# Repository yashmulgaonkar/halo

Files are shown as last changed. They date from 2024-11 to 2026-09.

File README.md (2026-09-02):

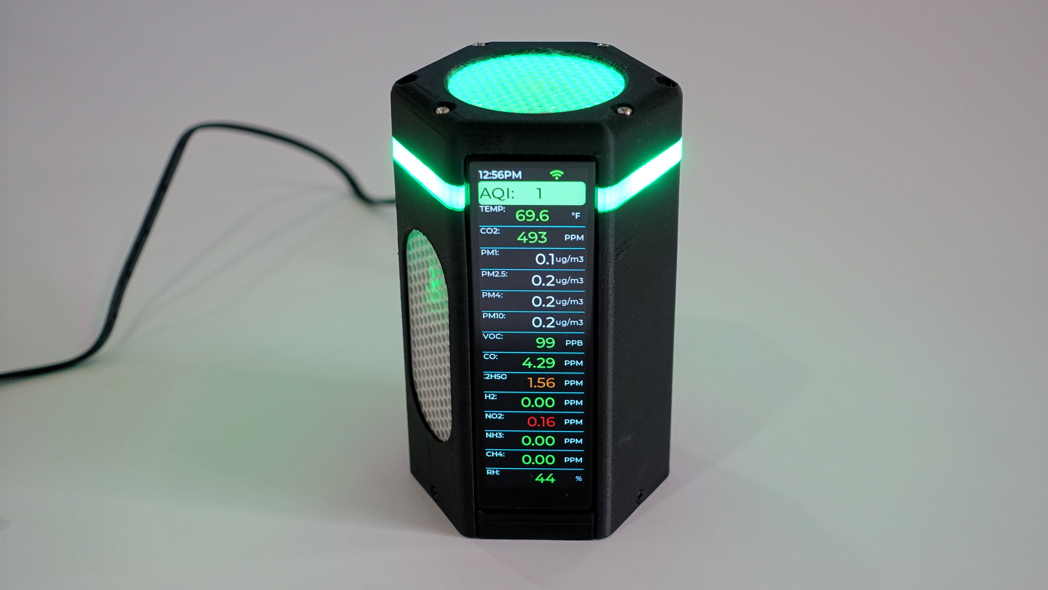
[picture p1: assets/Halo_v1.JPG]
Halo_v1


# HALO: The Air Quality Sensor That Smells Trouble Before You Do

Welcome to HALO — your hilariously over-engineered, open-source buddy who sniffs the air so you don’t have to. Designed for folks who care about the air they breathe but also want a sensor with personality, HALO operates on WiFi via ESPHome, which means no creepy cloud subscriptions or hidden fees. It’s just you, HALO, and your dusty air duking it out together.

---

## Features? Oh, HALO’s Got a Few Good Ones:

- **PM (Particulate Madness):** HALO tracks dust, pollen, and those mysterious floating things in the air. From “small but annoying” (PM2.5) to “call-the-vacuum” (PM10), HALO’s on it.
- **Sniffs Like a Dog:** HALO detects VOCs, CO₂, and gases like Ammonia, Ethanol, Methane, and Hydrogen. Basically, it’s like having a science lab shoved into a tiny box.
- **Weather Nerd:** HALO keeps tabs on temperature, humidity, and air pressure. It’s not your local weather station — it’s cooler.
- **Party Mode:** An eleven RGB LED HALO for air quality notifications or impromptu raves. Who said clean air can’t be fun?
- **Bluetooth Tracker:** HALO can help automate your home or, you know, find your keys if they’re Bluetooth-enabled.
- **Bluetooth & WiFi Powerhouse:** Includes BLE 5 + BT Mesh for seamless device integration and WiFi connectivity so HALO is always in the loop.
- **Touch of Brilliance:** A shiny new 3.4″ 640px × 180px LCD touchscreen for easy navigation and monitoring. Control HALO like a pro without even opening an app!

---

## Hardware Components

HALO is built with a powerhouse of components designed to sniff out, measure, and display air quality data with style. Here’s what makes HALO tick:

### MCU (Microcontroller Unit)
- **LILYGO T-Display-Long-S3:** The brains behind HALO, featuring an ESP32S3, a Dual-core LX7 MCU with a 3.4″ LCD touchscreen for easy interaction and a whole lot of smarts.

### Sensors
- **SCD-41:**
  - Measures CO₂ levels so you know when to crack a window open.
  - Tracks temperature because no one likes surprises.
  - Monitors humidity to keep your comfort levels in check.
- **SEN54 (or SEN55):**
  - Detects particulate matter: PM1, PM2.5, PM4, and PM10 (basically, HALO counts all the tiny stufflets floating around).
  - Measures VOC (Volatile Organic Compounds) to warn you about sketchy smells.
  - Also tracks temperature and humidity for full environmental awareness.
- **BME280:**
  - Keeps tabs on temperature, pressure, and humidity, because precision matters.
- **MIC4514:**
  - Sniffs out gases like:
    - CO (Carbon Monoxide)
    - C₂H₅OH (Ethanol)
    - H₂ (Hydrogen)
    - NO₂ (Nitrogen Dioxide)
    - NH₃ (Ammonia)
    - CH₄ (Methane)
- **Neopixels (11-LED ring):**
  - Side-fire **SK68XX-EC3210F** ([Adafruit #4892](https://cdn-shop.adafruit.com/product-files/4892/4892_SK68XX-EC3210F__REV.A.pdf)) — `NEO_GRB` + `NEO_KHZ800` / WS2812-compatible on GPIO47.

---

## Plug & Play? More Like Plug & Pray (Kidding — It’s Easy):

1. **Power Up:** Plug HALO into a decent USB-C power brick. If HALO starts rebooting like it’s stuck in a bad WiFi loop, blame your cheap charger. HALO deserves better.
2. **Find HALO’s Hotspot:** Look for the “HALO’s AP” network on your phone or computer. Connect, and voilà — HALO’s dashboard appears. If it doesn’t, just type `http://192.168.4.1`. Because nothing says “high-tech” like typing an IP address.
3. **Join Your WiFi:** Tell HALO your WiFi name and password. Pro tip: Maybe don’t name your WiFi “NSA Surveillance Van.” HALO’s judgment-free, but still.

---

## Home Assistant Integration: Because HALO Plays Well With Others

1. Add HALO to Home Assistant using ESPHome.
2. When prompted, click things like “Adopt” and “Submit.” It’s basically adopting a pet rock, except HALO is useful.
3. Give HALO a home area (kitchen, bedroom, dungeon — no judgment).

---

## What Does HALO Measure? Everything.

- **Particulates:** PM10, PM2.5, PM4, and PM1 – tiny ones you didn’t know existed. HALO’s the Sherlock Holmes of dust.
- **Gases:** From Nitrogen Dioxide (NO₂) to the Ammonia from your cat’s litter box, HALO’s got a nose for trouble.
- **Humidity & Temp:** Whether you’re sweating or freezing, HALO knows.
- **CO₂:** If your room feels stuffy, HALO will call you out.

---

## Fun Extras:

- **RGB Light Show:** HALO’s RGB LED halo can flash when your air quality is trash. It’s like HALO’s saying, “Get it together, human!”
- **Self-Calibrating Genius:** Just take HALO outside, and it’ll calibrate itself. HALO loves fresh air, too.

### Calibration & packages

- Sensor calibration (CO₂ ASC, SEN55 heat offsets, fan clean, NowCast): see [`TFT_LCD/T-Display-Long/V1/Firmware/ESPHome/CALIBRATION.md`](TFT_LCD/T-Display-Long/V1/Firmware/ESPHome/CALIBRATION.md)
- Optional modular packages (BLE stub, offline AQI history, weather, WireGuard): see [`TFT_LCD/T-Display-Long/V1/Firmware/ESPHome/PACKAGES.md`](TFT_LCD/T-Display-Long/V1/Firmware/ESPHome/PACKAGES.md)

---

## Troubleshooting? Call the HALO Hotline (AKA, Join Our Discord)

If HALO misbehaves, pop into our Discord for tips, tricks, and memes. HALO doesn’t judge your air, so don’t judge HALO’s quirks.

---

## Why HALO?

Because life’s too short for bad air and boring gadgets. HALO makes clean air monitoring fun, fabulous, and a little ridiculous.

### Open-Source for Open Minds
We love tinkerers, dreamers, and anyone who thinks, “You know what HALO really needs? A coffee maker attachment.” That’s why we’ve shared HALO’s software and CAD files with the world. Dive into our GitHub, unleash your inner mad scientist, and share your creations on Discord. Who knows? Your idea might just inspire HALO 2.0.

- **Build Instructions:** [https://github.com/yashmulgaonkar/halo/wiki](https://github.com/yashmulgaonkar/halo/wiki)
- **Discord:** [HALO Community](https://discord.gg/wjqgUjv8Re)

---

<div align="center"><strong>HALO: The sensor you didn’t know you needed — but now can’t live without.</strong></div>

---
<p align="center">
  <a href="https://buymeacoffee.com/yashmulgaonkar" target="_blank">
    Buy Me a Coffee
  </a>
</p>

---

Repo analytics (https://github.com/yashmulgaonkar/repo-analytics)

Repobeats analytics image

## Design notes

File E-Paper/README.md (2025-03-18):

Folder for Halo with an E-Paper display

The EPD version of Halo will use a [tricolor display from Waveshare](https://www.waveshare.com/2.9inch-e-paper-module-b.htm?&aff_id=108718) paired with a [ESP32-S3-Zero](https://www.waveshare.com/esp32-s3-zero.htm?sku=25517&aff_id=108718)

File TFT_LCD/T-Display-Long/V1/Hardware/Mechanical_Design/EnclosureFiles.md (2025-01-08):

# Halo AQI Enclosure Files

All 3D print files for the enclosure are available on the following platforms:





---

### How to Use These Files
1. Click one of the buttons above to access the 3D print files on your preferred platform.
2. Download the STL/STEP files.
3. Print the parts using your 3D printer and filaments of choice.
4. Assemble the enclosure following the project documentation on the [Halo Wiki](https://github.com/yashmulgaonkar/halo/wiki).

### Feedback and Contributions
Feel free to open an issue or submit a pull request if you encounter any issues or have suggestions for improvements.

---

### License
This project is licensed under the MIT License. See the [LICENSE](https://github.com/yashmulgaonkar/halo/blob/main/LICENSE) file for details.

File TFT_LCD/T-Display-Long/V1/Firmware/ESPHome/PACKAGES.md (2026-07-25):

# Modular packages (HALO)

## Cause of "Duplicate switch ... Startup Light Blink"

That switch lives only in `Halo-v1-Core.yaml`. It is duplicated when Core is
merged **twice**, usually because the device YAML `files:` list includes both:

- `Halo-v1.yaml` (which already pulls in Core), and
- `Halo-v1-Core.yaml` (again)

List **either** the entry file **or** the leaf packages — never both.

## Home Assistant — preferred (leaf packages once)

The NeoPixel driver lives at repo-root `components/ws2812_bitbang`.
HA leaf installs must load it via `external_components` **before** the packages
block (local `path:` only works for USB builds from this folder).

```yaml
esphome:
  name: halo-v1-4d1658
  friendly_name: Halo Air Quality Sensor 4d1658
  name_add_mac_suffix: false
  min_version: 2026.7.2

external_components:
  - source: github://yashmulgaonkar/halo@main
    components: [ws2812_bitbang]

ota:
  - platform: esphome
    id: ota_default

wifi:
  power_save_mode: none
  use_psram: true
  ap:
    ssid: "Halo Hotspot"

packages:
  remote_package:
    url: https://github.com/yashmulgaonkar/halo/
    ref: main
    refresh: 1d
    files:
      - TFT_LCD/T-Display-Long/V1/Firmware/ESPHome/packages/base/globals.yaml
      - TFT_LCD/T-Display-Long/V1/Firmware/ESPHome/packages/system/esphome_core.yaml
      - TFT_LCD/T-Display-Long/V1/Firmware/ESPHome/packages/features/ble/ble_stub.yaml
      - TFT_LCD/T-Display-Long/V1/Firmware/ESPHome/packages/features/airq/airq_history.yaml
      - TFT_LCD/T-Display-Long/V1/Firmware/ESPHome/packages/features/page_rotation/page_rotation.yaml
      - TFT_LCD/T-Display-Long/V1/Firmware/ESPHome/packages/features/ota/ota_channel.yaml
      - TFT_LCD/T-Display-Long/V1/Firmware/ESPHome/Halo-v1-Core.yaml
```

Do **not** add `Halo-v1.yaml` to that `files:` list.

Use `ble_improv.yaml` instead of `ble_stub.yaml` only when you need Improv
Wi-Fi provisioning (Bluedroid can worsen LED flicker under heavy radio load).

## Local / CI

[`Halo-v1.yaml`](Halo-v1.yaml) and [`Halo-v1-dev.yaml`](Halo-v1-dev.yaml) use
sibling `!include`s from this directory and a local `external_components` path
to `components/ws2812_bitbang` at the repo root.

```
packages/
  base/globals.yaml
  system/esphome_core.yaml
  features/ble/{ble_improv,ble_stub}.yaml
  features/airq/airq_history.yaml
  features/page_rotation/page_rotation.yaml
  features/ota/ota_channel.yaml
  features/weather/weather_ha.yaml      # optional
  features/wireguard/wireguard.yaml     # optional
```

Calibration: [`CALIBRATION.md`](CALIBRATION.md).

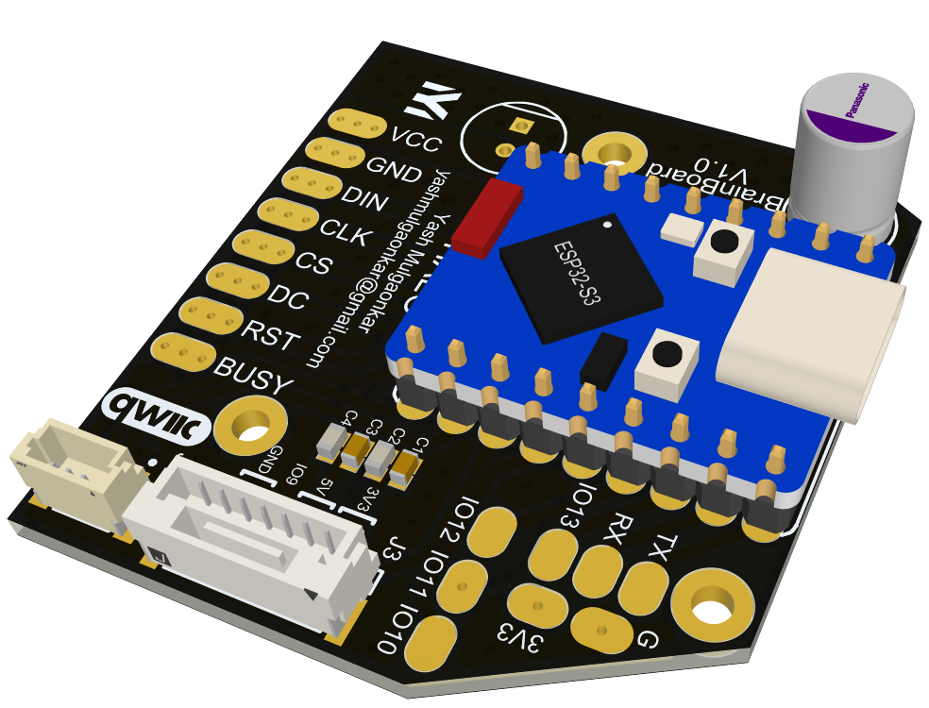
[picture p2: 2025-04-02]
E-Paper/Waveshare_BWR/V1/Hardware/Electrical_Design/BrainBoard/V1.0/Halo_BrainBoard_V1.0.png

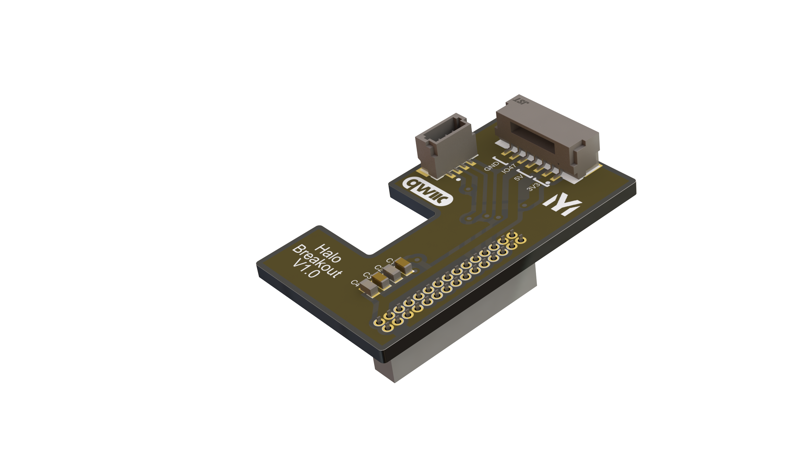
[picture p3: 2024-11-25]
TFT_LCD/T-Display-Long/V1/Hardware/Electrical_Design/Breakout/Halo_Breakout_V1.0.png

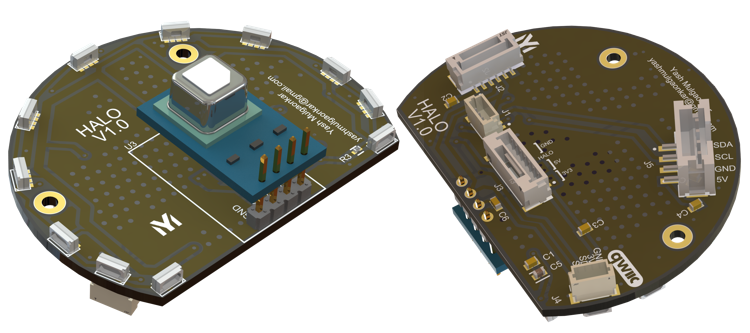
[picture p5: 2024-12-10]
assets/Halo_MainBoard_V1.0_1.png

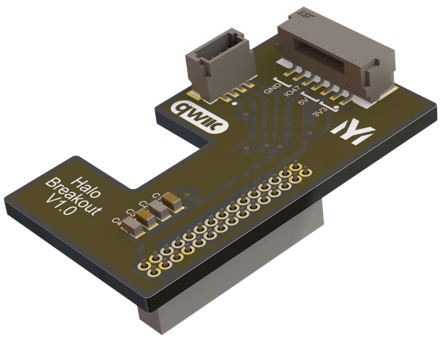
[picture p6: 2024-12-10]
assets/Halo_Breakout_V1.0.jpg

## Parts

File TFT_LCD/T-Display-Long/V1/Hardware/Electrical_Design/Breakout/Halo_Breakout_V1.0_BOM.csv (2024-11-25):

Designator | Quantity | Manufacturer | Manufacturer Part Number | Description
C1, C3 | 2 | YAGEO | CC0603ZRY5V9BB104 | 0.1 µF -20%, +80% 50V Ceramic Capacitor Y5V (F) 0603 (1608 Metric)
C2, C4 | 2 | YAGEO | CC0603KRX5R8BB105 | 1 µF ±10% 25V Ceramic Capacitor X5R 0603 (1608 Metric)
J1 | 1 | JST Sales America Inc. | SM07B-GHS-TB | Connector Header Surface Mount, Right Angle 7 position 0.049" (1.25mm)
J2 | 1 | JST Sales America Inc. | BM04B-SRSS-TBT | Connector Header Surface Mount 4 position 0.039" (1.00mm)
J3 | 1 | Amphenol ICC (FCI) | 20021311-00030T4LF | 30 Position Receptacle Connector 0.050" (1.27mm) Through Hole Gold

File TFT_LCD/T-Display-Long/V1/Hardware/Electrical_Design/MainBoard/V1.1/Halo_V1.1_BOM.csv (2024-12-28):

Designator | Quantity | Manufacturer | Manufacturer Part Number | Description
C1, C2, C3, C4, C6 | 5 | YAGEO | CC0603ZRY5V9BB104 | 0.1 µF -20%, +80% 50V Ceramic Capacitor Y5V (F) 0603 (1608 Metric)
C5 | 1 | Murata Electronics | GRM188R6YA106MA73D | 10 µF ±20% 35V Ceramic Capacitor X5R 0603 (1608 Metric)
J1, J4 | 2 | JST Sales America Inc. | BM04B-SRSS-TBT | Connector Header Surface Mount 4 position 0.039" (1.00mm)
J2 | 1 | JST Sales America Inc. | BM06B-GHS-TBT | Connector Header Surface Mount 6 position 0.049" (1.25mm)
J3 | 1 | JST Sales America Inc. | BM07B-GHS-TBT | Connector Header Surface Mount 7 position 0.049" (1.25mm)
J5 | 1 | JST Sales America Inc. | B4B-PH-SM4-TB | Connector Header Surface Mount 4 position 0.079" (2.00mm)
LED1, LED2, LED3, LED4, LED5, LED6, LED7, LED8, LED9, LED10 | 10 | Adafruit | 1655 | NeoPixel 5050 RGB LED with Integrated Driver
R3 | 1 | Vishay Dale | CRCW0402470RFKED | 470 Ohms ±1% 0.063W, 1/16W Chip Resistor 0402 (1005 Metric) Automotive AEC-Q200 Thick Film
U3 | 1 | Sensirion | SCD41 | HiLetgo SCD41 CO2 Carbon Dioxide Sensor (Amazon 14mm x 20mm modules)
U1 | 1 | Adafruit | 2226 | NeoPixel Jewel - 7 x 5050 RGB LED with Integrated Drivers

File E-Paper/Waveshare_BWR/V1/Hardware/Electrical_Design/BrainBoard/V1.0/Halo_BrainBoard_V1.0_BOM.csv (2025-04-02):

Designator | Quantity | Footprint | Manufacturer Part Number | Digi-Key Part Number | Comment
C1, C3 | 2 | CAPC1608X90X40LL10T20 |  |  | CC0603ZRY5V9BB104
C2, C4 | 2 | CAPC1608X90X35LL10T15 |  |  | GRM188R61E105KA12D
C5, C6 | 2 | FP-OS-CON-TH-C9-d_0_6-MFG |  |  | 6SEPC470MW+TSS
J2 | 1 | FP-BM04B-SRSS-TBT_LF_SN-MFG |  |  | BM04B-SRSS-TBT
J3 | 1 | FP-BM07B-GHS-TBT_LF_SN-MFG |  |  | BM07B-GHS-TBT (LF)(SN)
TP1, TP2, TP3, TP4, TP5, TP6, TP7, TP8 | 8 | test_pad |  |  | test_pad
U1 | 1 | ESP32-S3-Zero_headers |  |  | ESP32-S3-Zero
U2 | 1 | EPD |  |  | EPD

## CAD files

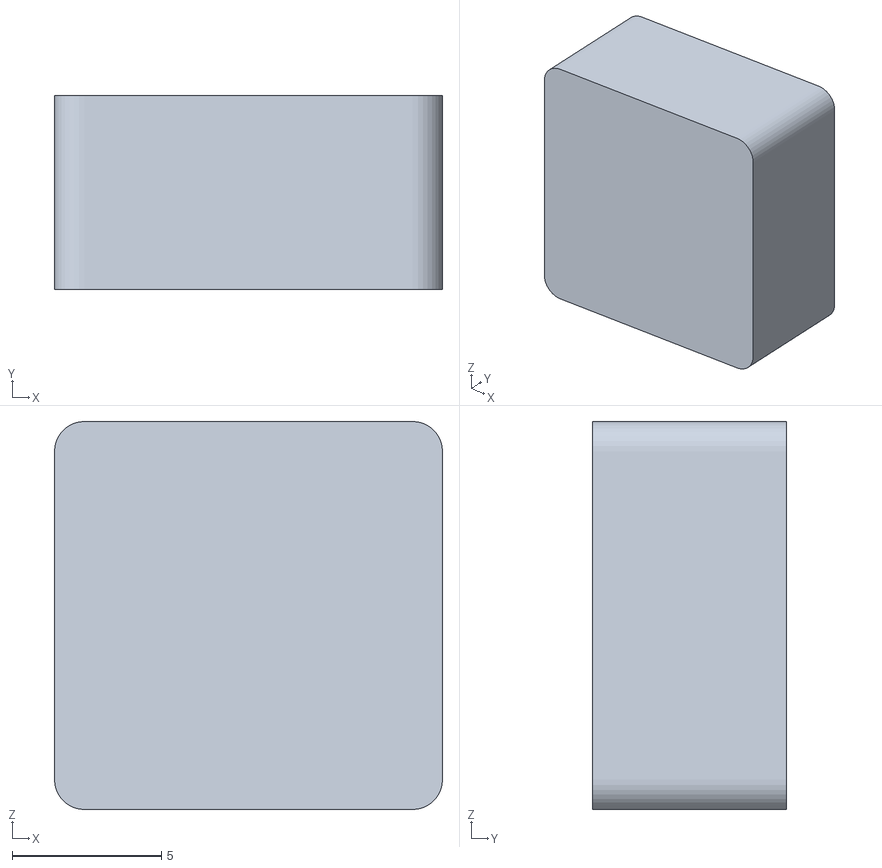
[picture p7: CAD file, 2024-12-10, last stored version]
V1/Hardware/Mechanical_Design/STLs/HALO_CO2_spacer.STL
13.0 x 6.50 x 13.0

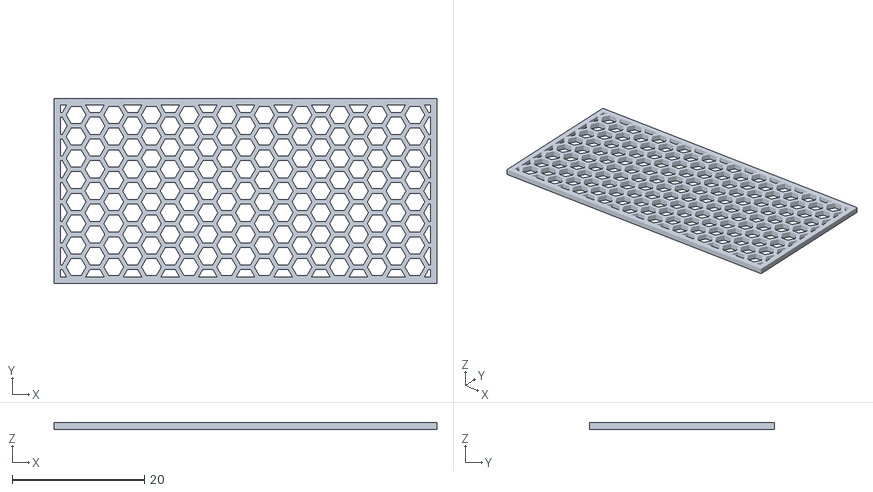
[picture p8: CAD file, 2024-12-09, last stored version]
V1/Hardware/Mechanical_Design/STLs/HALO_side_mesh.STL
58.0 x 28.0 x 1.00

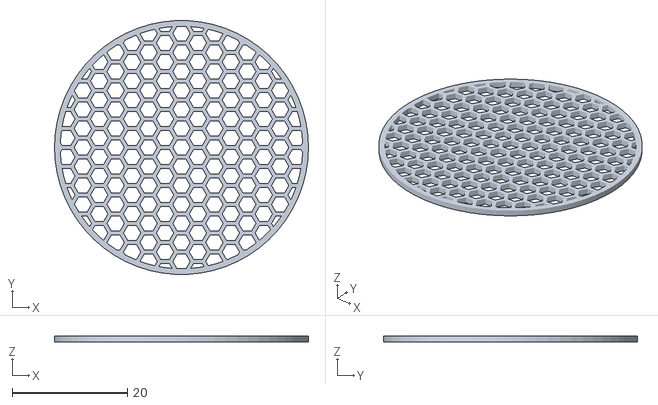
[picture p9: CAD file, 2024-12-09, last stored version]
V1/Hardware/Mechanical_Design/STLs/HALO_top_mesh.STL
44.0 x 43.9 x 1.00

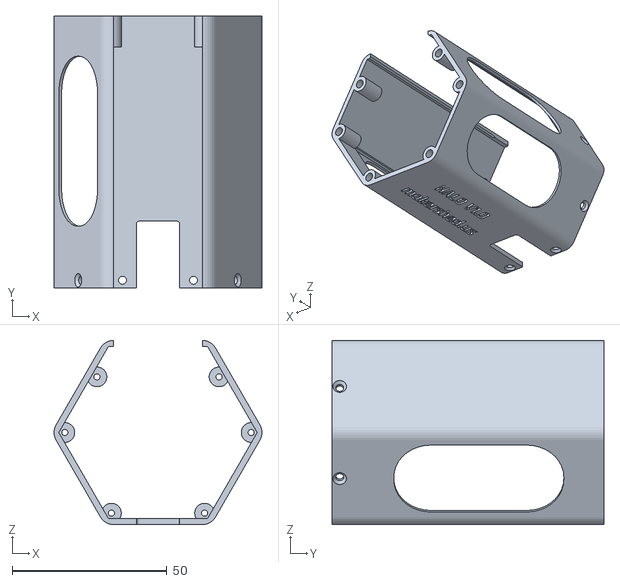
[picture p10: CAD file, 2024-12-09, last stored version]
V1/Hardware/Mechanical_Design/STLs/HALO_outer_shell.STL
67.3 x 88.0 x 59.6

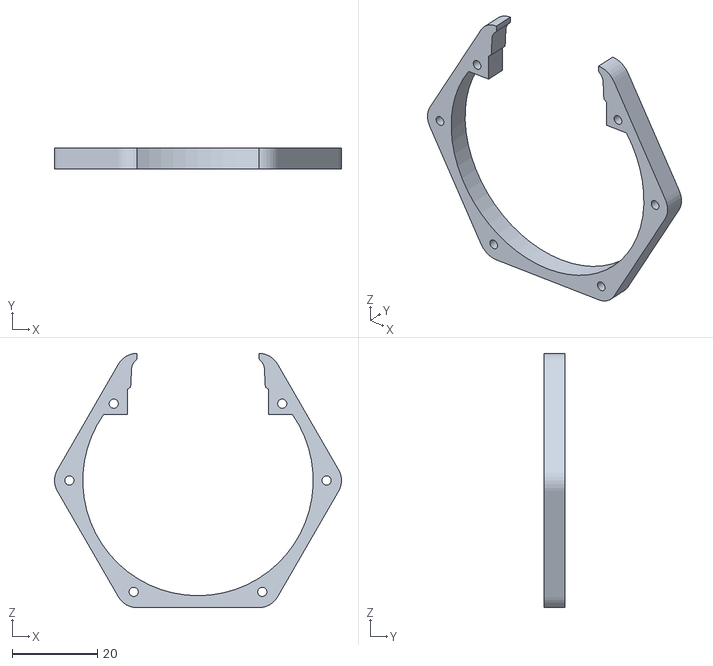
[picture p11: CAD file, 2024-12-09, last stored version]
V1/Hardware/Mechanical_Design/STLs/HALO_light_diffuser.STL
67.3 x 5.00 x 59.6

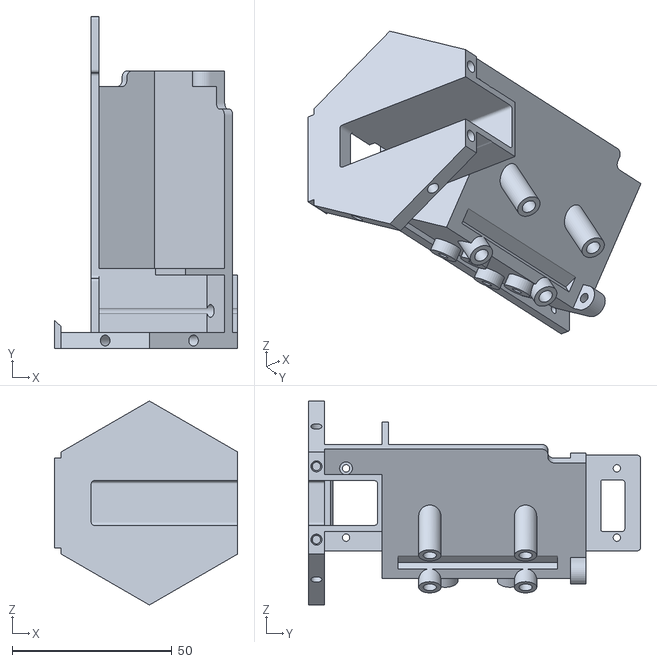
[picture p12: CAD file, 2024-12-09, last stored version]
V1/Hardware/Mechanical_Design/STLs/HALO_base.STL
57.5 x 104.0 x 63.9

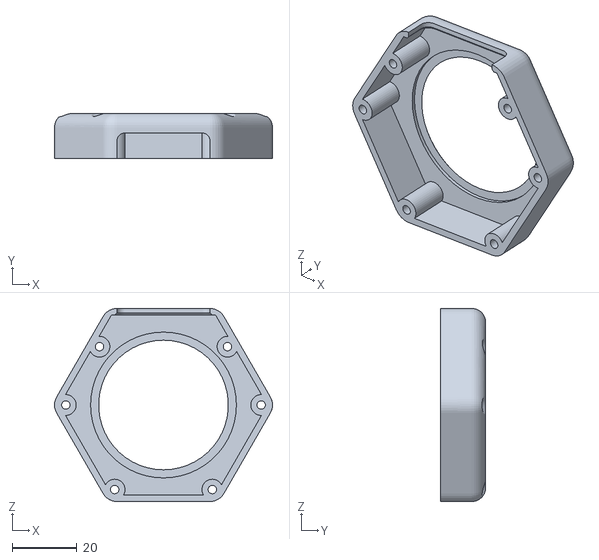
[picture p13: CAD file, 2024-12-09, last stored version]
V1/Hardware/Mechanical_Design/STLs/HALO_top_cap.STL
67.3 x 14.0 x 59.6

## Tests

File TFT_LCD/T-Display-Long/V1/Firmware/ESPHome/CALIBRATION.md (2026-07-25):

# Sensor calibration and heat management (HALO)

HALO shares the same sensor family as many ESPHome air-quality boards
(SCD4x, SEN55, MiCS-4514, BME280). These notes cover the controls exposed
in firmware on branch `feat/community-adoption`.

## CO₂ (SCD4x)

- **Forced calibration:** Home Assistant button `Calibrate SCD40 To 420ppm`,
  or API service `calibrate_co2_value` with a target ppm. Take the device
  outdoors (or to known fresh air) for several minutes before calibrating.
- **Automatic self-calibration (ASC):** Switch `CO2 Auto Calibration`.
  The SCD4x forgets ASC across power loss. HALO uses stop → write ASC →
  start periodic measurement so the command is accepted while idle.
- **Pressure compensation:** CO₂ readings use BME280 pressure as
  `ambient_pressure_compensation_source`.

## SEN55 temperature / humidity

- The USB-powered display board self-heats. Default
  **SEN55 Temperature Offset** is **6.0 °C** (subtracted from the raw
  reading). Tune the offset entity until SEN55 tracks a reference room
  thermometer.
- **SEN55 Humidity Offset** defaults to 0; adjust if RH is systematically
  high/low versus a reference.
- Continuous always-on reporting favors responsiveness over thermal
  settling. If you need better absolute T/RH accuracy, increase airflow
  around the vents and re-tune offsets after a 30+ minute warm-up.

## SEN55 model / NOx / fan clean

- Firmware forces `model: sen55` so NOx stays enabled on modules that
  misreport as SEN54 (requires ESPHome **2026.7.2+**).
- Button **Clean SEN55** (and API `sen55_clean`) runs the fan autoclean cycle.
- VOC index thresholds for the **VOC Quality** text sensor follow Sensirion
  guidance (Improved / Normal / Abnormal / …).

## AQI

- **Computed AQI** on the display is the on-device US EPA PM2.5 banding used
  by the LVGL UI.
- **NowCast AQI** is the native ESPHome `aqi` platform (PM2.5 + PM10) for
  Home Assistant — it does not replace the display math.

## Offline history

When the `airq_history` package is enabled (default), HALO buffers readings
in PSRAM while Home Assistant is unreachable and flushes
`esphome.aqi_history_batch` events on reconnect. Optional AppDaemon ingest
lives under [`HomeAssistant/AppDaemon/apps/`](../../../../HomeAssistant/AppDaemon/apps/).

## MiCS-4514 gases

Treat multi-gas readings as relative indicators, not safety-grade CO or
leak alarms. Cross-sensitivity (especially methane) is expected.

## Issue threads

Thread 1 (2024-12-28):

Missing Components

McRoth73, 2024-12-28:
I'm gathering the parts to make this and noticed that some pieces are missing from the BOM.  I don't see the 30 pin connector for the Lilygo board, whatever the 4 little cubes next to it the pic of it and the, I'm guessing, LED's around the perimeter of the semicircle board.  There may be others that I don't see.  Can you please add these and confirm that there aren't any other missing components?
Also, I ordered the V1.0 boards, are they going to work now that I see there is are V1.1 boards?

yashmulgaonkar, 2024-12-28:
Looks like you are looking for the Breakout board.
All relevant files are here:

https://github.com/yashmulgaonkar/halo/blob/main/V1/Hardware/Electrical_Design/Breakout

Closed 2024-12-28.

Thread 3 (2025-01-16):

ESP Home : Failed to build Error 522 YM.png

jfdl, 2025-01-16:
While trying to install your firmware on my board i got this error 522:

Could not download from https://yashmulgaonkar.com/YM.png: **522 Server Error**:  for url: https://yashmulgaonkar.com/YM.png.
file: https://yashmulgaonkar.com/YM.png

Is your site still online or is it a local issue ?

yashmulgaonkar, 2025-01-16:
This is correct. We have a major power outage so my server is offline at the moment. Please standby.

yashmulgaonkar, 2025-01-16:
I’ll take this as a motivation to move the online files away from a private server to GitHub.

yashmulgaonkar, 2025-01-16:
@jfdl Can you please the latest release now?

jfdl, 2025-01-17:
It is working fine now.
Thanks

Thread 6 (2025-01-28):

PCB Dimensions?

wanball, 2025-01-28:
Sorry for my English.

Can you tell me the dimensions of Halo MainBoard and Halo Breakout?

Since my soldering skill is quite bad, I want to modify the PCB myself to suit my soldering and change some connectors so that I can buy them.

Thanks for your attention.

wanball, 2025-01-28:
I would like to ask one more question, can I increase the thickness to 2mm?

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

yashmulgaonkar, 2025-02-18:
@wanball all PCB CAD files for dimensions are available in the repo.
If you increase the thickness to 2mm, make sure to also increase the clearance in the outer shell  to accommodate the thicker mesh.

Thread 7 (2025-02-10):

Trying to upload bom and pick&place for breakout pcb to JLCPCB

greberg, 2025-02-10:
Hi

Im trying to upload the bom and pick&place files for the breakout card to JLCPCB but when I choose process files I get a error message that says "File processing failed, please check your file and upload again." I wonder if it is any fault into the P&P breakout file. Not sure if it could be about the coordinates?  Maybe it has changed on JLCPCB side?

https://github.com/yashmulgaonkar/halo/blob/main/TFT_LCD/T-Display-Long/V1/Hardware/Electrical_Design/Breakout/Pick%20Place%20for%20Halo_Breakout_V1.0.csv

Best regards
Peter

greberg, 2025-02-11:
Found a new bom file in discord that worked.

https://discord.com/channels/1309649507310506115/1309649802811670669/1333982233605967944

MaffooClock, 2025-04-11:
For anyone attempting to follow the link above, but getting an error, you need to be accepted to the Makershed.us discord first:
https://discord.gg/wjqgUjv8Re

Better yet, I'll save you the trouble just paste the damn CSVs from the above-linked comment:
```csv
Description,Designator,Footprint,JLCPCB Part #,Manufacturer,Manufacturer Part Number
"0.1 µF -20%, +80% 50V Ceramic Capacitor Y5V (F) 0603 (1608 Metric)","C1, C2, C3, C4, C6",C0603,C106221,YAGEO,CC0603ZRY5V9BB104
10 µF ±20% 35V Ceramic Capacitor X5R 0603 (1608 Metric),C5,C0603,C194427,Murata Electronics,GRM188R6YA106MA73D
"Connector Header Surface Mount 4 position 0.039"" (1.00mm)","J1, J4",CONN-SMD_BM04B-SRSS-TBT-LF-SN,C495539,JST Sales America Inc.,BM04B-SRSS-TBT
"Connector Header Surface Mount 6 position 0.049"" (1.25mm)",J2,CONN-SMD_6P-P1.25_BM06B-GHS-TBT-LF-SN-N,C189892,JST Sales America Inc.,BM06B-GHS-TBT
"Connector Header Surface Mount 7 position 0.049"" (1.25mm)",J3,CONN-SMD_SM7B-GHS-TB-LF-SN,C495552,JST Sales America Inc.,BM07B-GHS-TBT
"Connector Header Surface Mount 4 position 0.079"" (2.00mm)",J5,CONN-SMD_B4B-PH-SM4-TB-LF-SN,C160354,JST Sales America Inc.,B4B-PH-SM4-TB
"470 Ohms ±1% 0.063W, 1/16W Chip Resistor 0402 (1005 Metric) Automotive AEC-Q200 Thick Film",R3,R0402,C482182,Vishay Dale,CRCW0402470RFKED
4 pin LED,"LED1, LED2, LED3, LED4, LED5, LED6, LED7, LED8, LED9, LED10",LED-SMD_4P-L5.0-W5.0-LS5.4-TL-1,C5378720,OPSCO Optoelectronics,SK6812
```

```csv
Comment,Designator,Footprint,JLCPCB Part #
"0.1 µF -20%, +80% 50V Ceramic Capacitor Y5V (F) 0603 (1608 Metric)","C1, C3",C0603,C106221
1 µF ±10% 25V Ceramic Capacitor X5R 0603 (1608 Metric),"C2, C4",C0603,C14664
"Connector Header Surface Mount, Right Angle 7 position 0.049"" (1.25mm)",J1,CONN-SMD_SM7B-GHS-TB-LF-SN,C495552
"Connector Header Surface Mount 4 position 0.039"" (1.00mm)",J2,CONN-SMD_BM04B-SRSS-TBT-LF-SN,C495539
"30 Position Receptacle Connector 0.050"" (1.27mm) Through Hole Gold",J3,HDR-TH_30P-P2.54-V-F-R2-C15-S2.54,C9900022973
```

Closed 2025-02-11.

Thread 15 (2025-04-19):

ESPHome Builder: TypeError: spi_device_schema() got an unexpected keyword argument 'quad'

MaffooClock, 2025-04-19:
While following the [Setup Instructions](https://github.com/yashmulgaonkar/halo/wiki/Software-Setup), when I get to the step after I copy the [Halo-v1.yaml](https://github.com/yashmulgaonkar/halo/blob/main/TFT_LCD/T-Display-Long/V1/Firmware/ESPHome/Halo-v1.yaml) to the newly-created device, then attempt to install, I get this:

```text
INFO ESPHome 2025.4.0
INFO Reading configuration /config/esphome/halo.yaml...
INFO Updating https://github.com/yashmulgaonkar/halo/@main
ERROR Unable to load component axs15231.display:
Traceback (most recent call last):
  File "/esphome/esphome/loader.py", line 181, in _lookup_module
    module = importlib.import_module(f"esphome.components.{domain}")
             ^^^^^^^^^^^^^^^^^^^^^^^^^^^^^^^^^^^^^^^^^^^^^^^^^^^^^^^
  File "/usr/lib/python3.11/importlib/__init__.py", line 126, in import_module
    return _bootstrap._gcd_import(name[level:], package, level)
           ^^^^^^^^^^^^^^^^^^^^^^^^^^^^^^^^^^^^^^^^^^^^^^^^^^^^
  File "<frozen importlib._bootstrap>", line 1206, in _gcd_import
  File "<frozen importlib._bootstrap>", line 1178, in _find_and_load
  File "<frozen importlib._bootstrap>", line 1149, in _find_and_load_unlocked
  File "<frozen importlib._bootstrap>", line 690, in _load_unlocked
  File "<frozen importlib._bootstrap_external>", line 940, in exec_module
  File "<frozen importlib._bootstrap>", line 241, in _call_with_frames_removed
  File "/data/external_components/2a89883c/components/axs15231/display/__init__.py", line 72, in <module>
    spi.spi_device_schema(
TypeError: spi_device_schema() got an unexpected keyword argument 'quad'
Failed config

display.axs15231: [source /data/packages/ade47543/TFT_LCD/T-Display-Long/V1/Firmware/ESPHome/Halo-v1-Core.yaml:167]

  Platform not found: 'display.axs15231'.
  platform: axs15231
  id: lily_display
  spi_id: lily_spi
  dimensions:
    height: 640
    width: 180
  cs_pin: 12
  reset_pin: 16
  rotation: 0
  auto_clear_enabled: False
```

Note that the error displayed is misleading -- "Platform not found" isn't the real error; the real error is that the `quad` value for the `type` option under the `spi` stanza in the [Halo-v1-Core.yam](https://github.com/yashmulgaonkar/halo/blob/53fa635e02788e07287a9aeafbbc1eaa73e0d309/TFT_LCD/T-Display-Long/V1/Firmware/ESPHome/Halo-v1-Core.yaml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)l file is apparently a problem, which [doesn't make sense at all](https://esphome.io/components/spi.html).

I've never used ESPHome before, so this is a fresh install of ESPHome Builder into an up-to-date instance of Home Assistant (and everything else works fine).  I messed with this for a few hours, trying different things, and even removing ESPHome Builder (including all configs) and trying again with the beta version... nothing I do gives me _any_ different behavior than exactly this error 100% of the time.

I have to believe this is just me, since everyone else seems to be enjoying their Halo just fine.  I checked Discord and Google for answers, got nowhere.

MaffooClock, 2025-04-19:
I think I (er, well, @dkowis did) found the bug.  It's in your custom [axs15231 component](https://github.com/yashmulgaonkar/esphome-components/blob/main/components/axs15231)... specifically [this](https://github.com/yashmulgaonkar/esphome-components/blob/4ca0dac762cc83aff6c565db84e7a5c961316732/components/axs15231/display/__init__.py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):

```python
            spi.spi_device_schema(
                cs_pin_required=False,
                default_mode="MODE0",
                default_data_rate=20e6,
                quad=True,
            )
```

The [current implementation](https://github.com/esphome/esphome/blob/71afd49e3e0f1984d4318130c0007bb19f49318f/esphome/components/spi/__init__.py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) is different:

```python
def spi_device_schema(
    cs_pin_required=True,
    default_data_rate=cv.UNDEFINED,
    default_mode=cv.UNDEFINED,
    mode=TYPE_QUAD,
):
```

Closed 2025-08-24.

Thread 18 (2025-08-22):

No longer boots with esphome 2025.8.0

edbgon, 2025-08-22:
After updating today with esphome 2025.8.0, the esp32 is not starting and screen remains black. I can still upload, so it's not bricked, but there is something causing a panic.

Perhaps this can serve as a warning to those looking to use the latest esphome.

```
[09:42:01]I (341) esp_image: segment 5: paddr=001b6a78 vaddr=600fe000 sizeE (699) MSPI Timing: The flash model has not been verified support this feature, please contact espressif business support
[09:42:01]E (700) cpu_start: init function 0x4038120c has failed (0x106), aborting

[09:42:01]abort() was called at PC 0x4209f9ef on core 0

[09:42:01]Backtrace: 0x4037887d:0x3fceb1e0 0x403848a1:0x3fceb200 0x4038c84e:0x3fceb220 0x4209f9ef:0x3fceb290 0x4209fa13:0x3fceb2b0 0x403781b1:0x3fceb2e0 0x403ccad4:0x3fceb340 0x403ccf11:0x3fceb380 0x403c8975:0x3fceb4b0 0x40045c01:0x3fceb570 0x40043ab6:0x3fceb6f0 0x40034c45:0x3fceb710
WARNING Found stack trace! Trying to decode it
WARNING Decoded 0x4037887d: panic_abort at /home/bobris/.platformio/packages/framework-espidf/components/esp_system/panic.c:469
WARNING Decoded 0x403848a1: esp_system_abort at /home/bobris/.platformio/packages/framework-espidf/components/esp_system/port/esp_system_chip.c:87
WARNING Decoded 0x4038c84e: abort at /home/bobris/.platformio/packages/framework-espidf/components/newlib/abort.c:38
WARNING Decoded 0x4209f9ef: do_system_init_fn at /home/bobris/.platformio/packages/framework-espidf/components/esp_system/startup.c:135
WARNING Decoded 0x4209fa13: do_secondary_init at /home/bobris/.platformio/packages/framework-espidf/components/esp_system/startup.c:184
 (inlined by) start_cpu0_default at /home/bobris/.platformio/packages/framework-espidf/components/esp_system/startup.c:210
WARNING Decoded 0x403781b1: call_start_cpu0 at /home/bobris/.platformio/packages/framework-espidf/components/esp_system/port/cpu_start.c:849 (discriminator 1)

[09:42:03]ELF file SHA256: a50c15595

[09:42:03]Rebooting...
[09:42:03]ESP-ROM:esp32s3-20210327
[09:42:03]Build:Mar 27 2021
[09:42:03]rst:0xc (RTC_SW_CPU_RST),boot:0x28 (SPI_FAST_FLASH_BOOT)
[09:42:03]Saved PC:0x403787c1
WARNING Decoded 0x403787c1: esp_restart_noos at /home/bobris/.platformio/packages/framework-espidf/components/esp_system/port/soc/esp32s3/system_internal.c:162
[09:42:03]SPIWP:0xee
[09:42:03]mode:DIO, clock div:1
[09:42:03]load:0x3fce2820,len:0x1564
[09:42:03]load:0x403c8700,len:0x4
[09:42:03]load:0x403c8704,len:0xc84
[09:42:03]load:0x403cb700,len:0x2f00
[09:42:03]entry 0x403c890c
[09:42:03]I (26) boot: ESP-IDF 5.4.2 2nd stage bootloader
[09:42:03]I (26) boot: compile time Aug 22 2025 09:38:29
[09:42:03]I (26) boot: Multicore bootloader
[09:42:03]I (27) boot: chip revision: v0.2
[09:42:03]I (27) boot: efuse block revision: v1.3
[09:42:03]I (28) boot.esp32s3: Boot SPI Speed : 80MHz
[09:42:03]I (28) boot.esp32s3: SPI Mode       : DIO
[09:42:03]I (29) boot.esp32s3: SPI Flash Size : 16MB
[09:42:03]I (29) boot: Enabling RNG early entropy source...
[09:42:03]I (30) boot: Partition Table:
[09:42:03]I (30) boot: ## Label            Usage          Type ST Offset   Length
[09:42:03]I (31) boot:  0 otadata          OTA data         01 00 00009000 00002000
[09:42:03]I (32) boot:  1 phy_init         RF data          01 01 0000b000 00001000
[09:42:03]I (33) boot:  2 app0             OTA app          00 10 00010000 007c0000
[09:42:03]I (34) boot:  3 app1             OTA app          00 11 007d0000 007c0000
[09:42:03]I (35) boot:  4 nvs              WiFi data        01 02 00f90000 0006d000
[09:42:03]I (36) boot: End of partition table
[09:42:03]I (37) esp_image: segment 0: paddr=00010020 vaddr=3c140020 size=507ach (329644) map
[09:42:03]I (96) esp_image: segment 1: paddr=000607d4 vaddr=3fca2000 size=054a0h ( 21664) load
[09:42:03]I (101) esp_image: segment 2: paddr=00065c7c vaddr=40374000 size=0a39ch ( 41884) load
[09:42:03]I (111) esp_image: segment 3: paddr=00070020 vaddr=42000020 size=132e04h (1256964) map
[09:42:03]I (333) esp_image: segment 4: paddr=001a2e2c vaddr=4037e39c size=13c44h ( 80964) load
[09:42:03]I (352) esp_image: segment 5: paddr=001b6a78 vaddr=600fe000 size=0001ch (    28) load
[09:42:03]I (363) boot: Loaded app from partition at offset 0x10000
[09:42:03]I (364) boot: Disabling RNG early entropy source...
```

edbgon, 2025-08-22:
Forcing the following seems to work

    platform_version: 6.9.0
    version: 5.3.1

I haven't tried to find closer/newer values, but at least things are up and running again :)

yashmulgaonkar, 2025-08-24:
ESPHome bugs resolved! Firmware: 25.8.23.2 (ESPHome 2025.8.0) should work as intended.

Known bugs:
Halo LEDs may show incorrect colors / flicker randomly. This is due to a bug in ESPHome 2025.8.0.

Closed 2025-08-24.

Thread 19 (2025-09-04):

Blank display after installing on ESP Home 2025.8.0, 8.1,8.2, 8.3

horspiste, 2025-09-04:
Ever since I updated my Halo device with ESP Home 2025.8.0, I get the blank display problem. I have cleaned the build files and trying to upload again (usb connected with ESP Home Web since wireless isn't working anymore) and it still doesn't work.

Here is the log i can get from ESP Home Web:

[16:37:36]I (323) esp_image: segment 4: paddr=001a2c44 vaddr=4037e13c sizeE (706) MSPI Timing: The flash model has not been verified support this feature, please contact espressif business support
[16:37:36]E (707) cpu_start: init function 0x4038112c has failed (0x106), aborting
[16:37:36]
[16:37:36]abort() was called at PC 0x4209f8cf on core 0
[16:37:36]
[16:37:36]
[16:37:36]Backtrace: 0x403787e9:0x3fceb1e0 0x403847c1:0x3fceb200 0x4038c76e:0x3fceb220 0x4209f8cf:0x3fceb290 0x4209f8f3:0x3fceb2b0 0x4037811d:0x3fceb2e0 0x403ccad4:0x3fceb340 0x403ccf11:0x3fceb380 0x403c8975:0x3fceb4b0 0x40045c01:0x3fceb570 0x40043ab6:0x3fceb6f0 0x40034c45:0x3fceb710
[16:37:36]
[16:37:36]
[16:37:36]
[16:37:36]
[16:37:36]ELF file SHA256: d340b74b9
[16:37:36]
[16:37:36]Rebooting...
[16:37:36]ESP-ROM:esp32s3-20210327
[16:37:36]Build:Mar 27 2021
[16:37:36]rst:0xc (RTC_SW_CPU_RST),boot:0x28 (SPI_FAST_FLASH_BOOT)
[16:37:36]Saved PC:0x4037872d
[16:37:36]SPIWP:0xee
[16:37:36]mode:DIO, clock div:1
[16:37:36]load:0x3fce2820,len:0x1564
[16:37:36]load:0x403c8700,len:0x4
[16:37:36]load:0x403c8704,len:0xc84
[16:37:36]load:0x403cb700,len:0x2f00
[16:37:36]entry 0x403c890c
[16:37:36]I (26) boot: ESP-IDF 5.4.2 2nd stage bootloader
[16:37:36]I (26) boot: compile time Sep  4 2025 16:34:01
[16:37:36]I (26) boot: Multicore bootloader
[16:37:36]I (27) boot: chip revision: v0.2
[16:37:36]I (27) boot: efuse block revision: v1.3
[16:37:36]I (27) boot.esp32s3: Boot SPI Speed : 80MHz
[16:37:36]I (27) boot.esp32s3: SPI Mode       : DIO
[16:37:36]I (27) boot.esp32s3: SPI Flash Size : 16MB
[16:37:36]I (27) boot: Enabling RNG early entropy source...
[16:37:36]I (28) boot: Partition Table:
[16:37:36]I (28) boot: ## Label            Usage          Type ST Offset   Length
[16:37:36]I (28) boot:  0 otadata          OTA data         01 00 00009000 00002000
[16:37:36]I (29) boot:  1 phy_init         RF data          01 01 0000b000 00001000
[16:37:36]I (29) boot:  2 app0             OTA app          00 10 00010000 007c0000
[16:37:36]I (29) boot:  3 app1             OTA app          00 11 007d0000 007c0000
[16:37:36]I (30) boot:  4 nvs              WiFi data        01 02 00f90000 0006d000
[16:37:36]I (30) boot: End of partition table
[16:37:36]I (30) esp_image: segment 0: paddr=00010020 vaddr=3c140020 size=50a0ch (330252) map
[16:37:36]I (89) esp_image: segment 1: paddr=00060a34 vaddr=3fca2000 size=054a0h ( 21664) load
[16:37:36]I (94) esp_image: segment 2: paddr=00065edc vaddr=40374000 size=0a13ch ( 41276) load
[16:37:36]I (103) esp_image: segment 3: paddr=00070020 vaddr=42000020 size=132c1ch (1256476) map
[16:37:36]I (325) esp_image: segment 4: paddr=001a2c44 vaddr=4037e13c size=13dc4h ( 81348) load
[16:37:36]I (343) esp_image: segment 5: paddr=001b6a10 vaddr=600fe000 size=0001ch (    28) load
[16:37:36]I (355) boot: Loaded app from partition at offset 0x10000
[16:37:36]I (355) boot: Disabling RNG early entropy source...

boctok, 2025-09-06:
I got this as well. I even tried installing a factory sketch (the flip clock) to check the functionality of the screen and it's still black. Could this have fried something in the screen? Did we just get screens from a bad batch? I have another on the way, but I'm reluctant to install, until this gets fixed.

horspiste, 2025-09-07:
I managed to install a factory sketch (GFX_AXS15231B_Image) and it worked, the display and touch worked. Tried to reinstall the Halo firmware with esphome web and it installs but does not start. Display is blank, not connected to wifi.

boctok, 2025-09-07:
I tried that one too, but I have some library conflicts that I need to figure out.

edbgon, 2025-09-07:
Since the later versions of esphome are blocking downgrading the platformIO version, the only way I've been able to get it working again is to install esphome 2025.7.3 and download over USB.

horspiste, 2025-09-07:
I did some tests on a fork, if I remove the PSRAM speed (was 120) and leave it default, the device boots, the display initialise and it crashes after a while. If I unplug the sensors (except the SCD41 which is soldered)  then it stops crashing. As soon as I plug one of the other 3 sensors, it starts a crash loop. The SCD41 readings are logged properly.

yashmulgaonkar, 2025-09-08:
This is unfortunate! I am unable to replicate this issue - @horspiste can you plug in one sensor at a time and let me know which one crashes the Halo?

yashmulgaonkar, 2025-09-09:
Folks, can you please install Firmware: 25.9.8.1 (ESPHome 2025.8.3)? and let me know if that solves your issues?

edbgon, 2025-09-09:
Just synced your repo and loaded with 2025.8.3 and everything looks good.

Closed 2025-09-09.

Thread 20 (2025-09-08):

Updated BOM electronics list

Sleepy81, 2025-09-08:
The Gravity: MEMS Gas Sensor (CO, Alcohol, NO2 and amp, NH3) - I2C - MiCS-4514 (SEN0377) is no longer being produced and is hard to find/impossible to buy depending on your country. Also the Qwiic Cable (50mm) (PRT-17260) is not available from many stores and hard to find.

Any chance of an updated V2 of the HALO with new sensors and updated BOM?

yashmulgaonkar, 2025-09-10:
Thanks so much for pointing this out! When I first built the Halo, I grabbed a small stash of the MiCS-4514 sensors, so I’m still using those for now. Since this is a side project I fund and work on in my spare time, I don’t have plans just yet for a new hardware revision.

The good news is there are other sensors that can take the place of the MiCS-4514, like the [SGP40](https://www.adafruit.com/product/4829), [ENS160](https://www.adafruit.com/product/5606), or [MiCS-5524](https://www.adafruit.com/product/3199). The Halo’s config files are set up so you can swap in one of these pretty easily with a little editing.

If anyone in the community tries out these alternatives, please share your results, it would be awesome to see what works best and it could help shape a future “Halo V2” together!

Closed 2025-09-10.

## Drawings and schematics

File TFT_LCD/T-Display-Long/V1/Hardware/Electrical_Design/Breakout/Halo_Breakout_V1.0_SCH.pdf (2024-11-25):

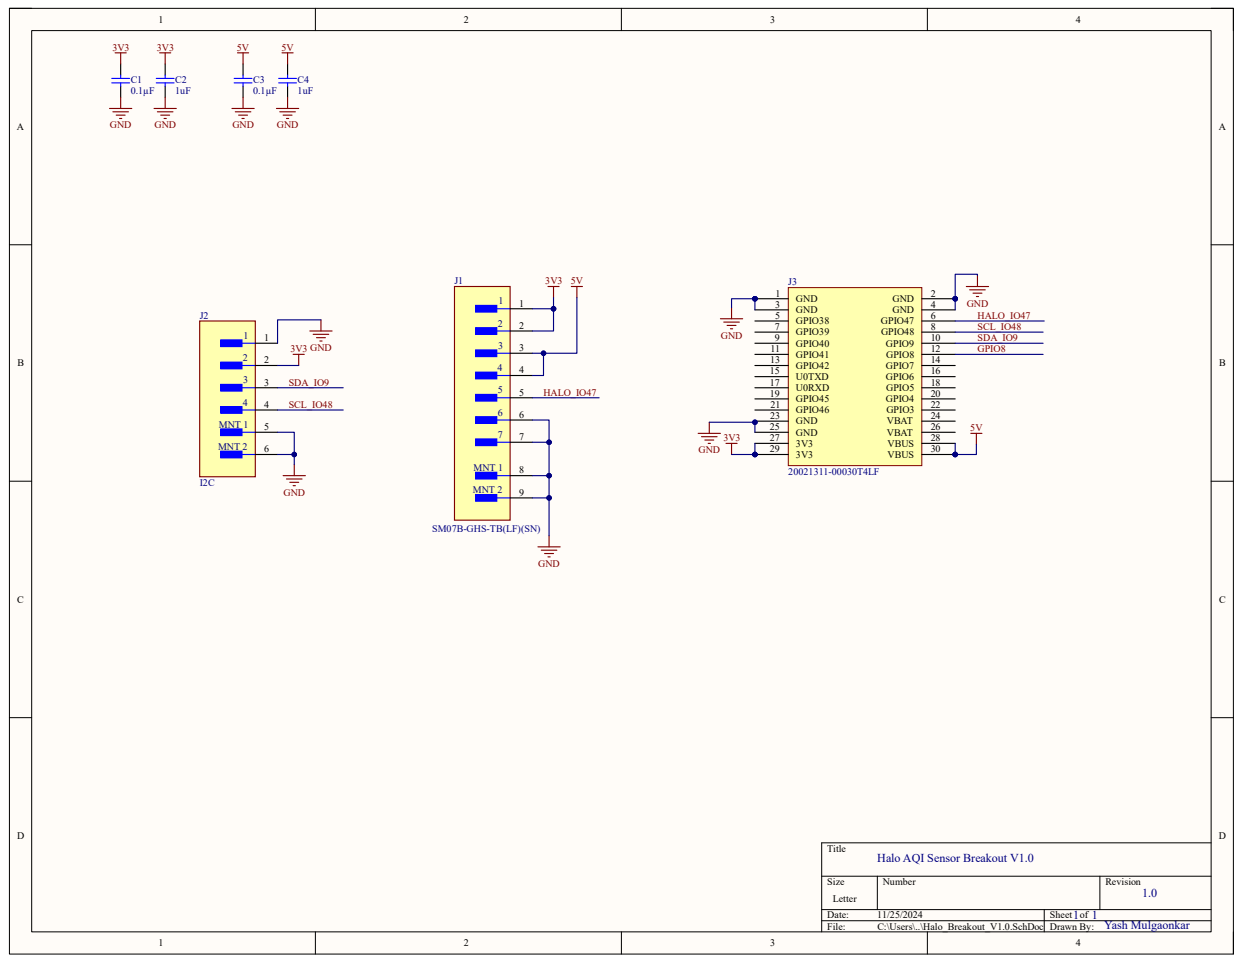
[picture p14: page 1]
Title; Size; Number; Revision; Letter; Date:; Sheet of; File:; C:\Users\..\Halo_Breakout_V1.0.SchDoc; Drawn By:; HALO_IO47; GND; MNT 1; MNT 2; 3V3 GND; SDA_IO9; SCL_IO48; 2 GND 1; 4 GND 3; GPIO47; 6 GPIO38 5; GPIO48; 8 GPIO39 7; GPIO9; 10 GPIO40 9; GPIO8; 12 GPIO41 11; GPIO7; 14 GPIO42 13; GPIO6; 16 U0TXD 15; GPIO5; 18 U0RXD 17; GPIO4; 20 GPIO45 19; GPIO3; 22 GPIO46 21; VBAT; 24 GND 23; 26 GND 25; VBUS; HALO_IO47 SCL_IO48 SDA_IO9 GPIO8; Yash Mulgaonkar

SM07B-GHS-TB(LF)(SN)

Halo AQI Sensor Breakout V1.0

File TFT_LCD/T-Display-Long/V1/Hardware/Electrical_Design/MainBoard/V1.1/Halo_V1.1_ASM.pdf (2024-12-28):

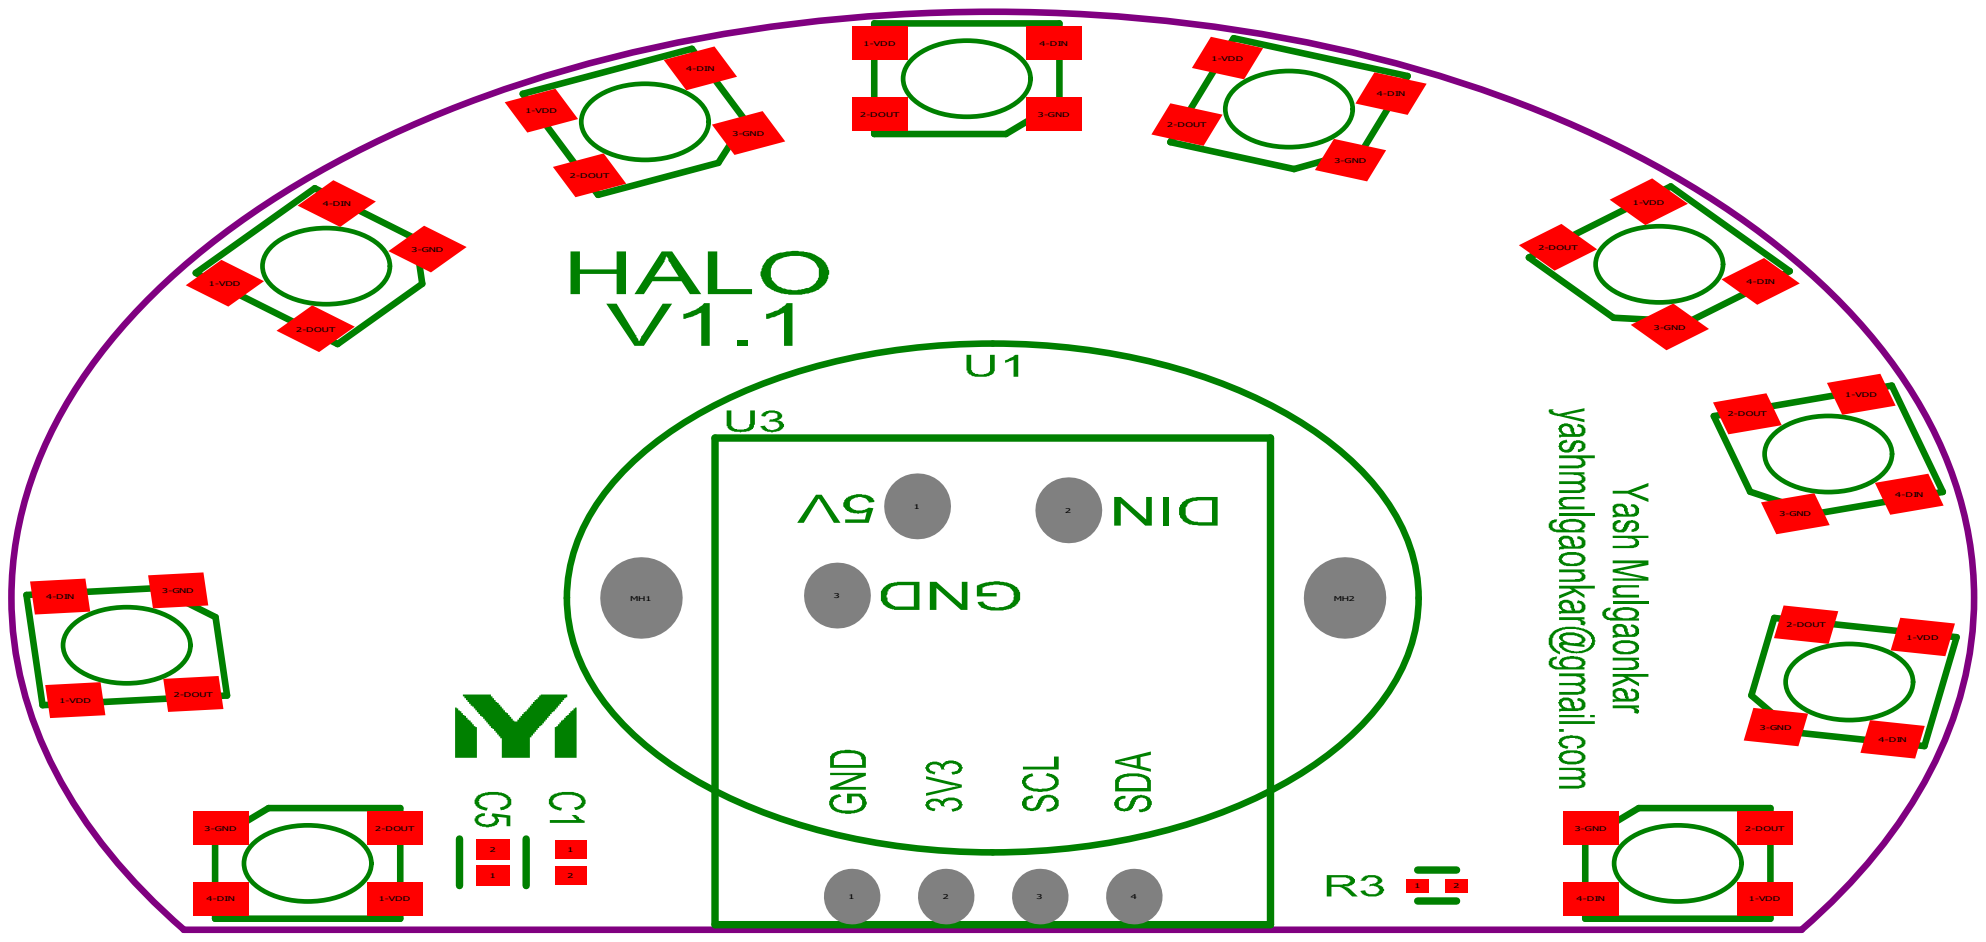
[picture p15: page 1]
3-GND; 4-DIN; 2-DOUT; 1-VDD

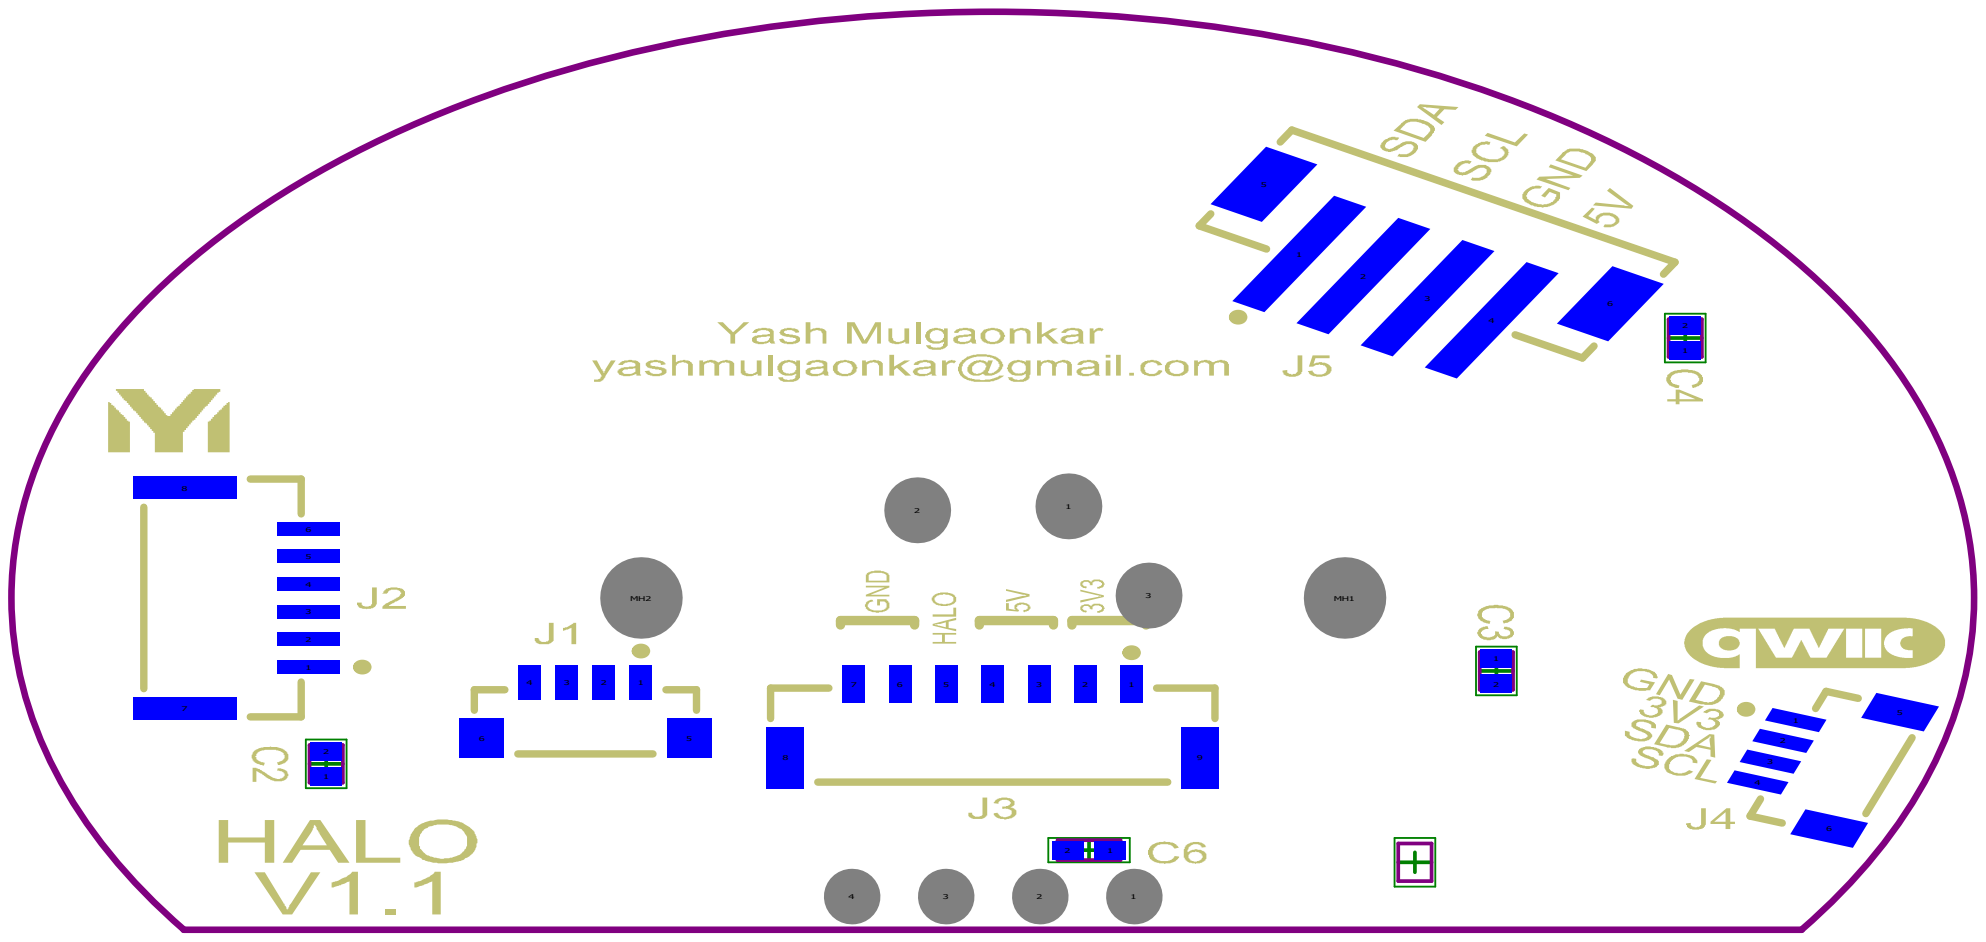
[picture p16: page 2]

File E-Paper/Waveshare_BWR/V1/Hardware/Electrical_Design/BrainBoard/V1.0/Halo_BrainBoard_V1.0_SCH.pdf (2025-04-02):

IO7 | 10 IO8 | 11 IO9 | 12 IO10 | 13 IO11 | 14 IO12 | 15 IO13 | 16 RX | 17 TX | 18

# GND¹ ²

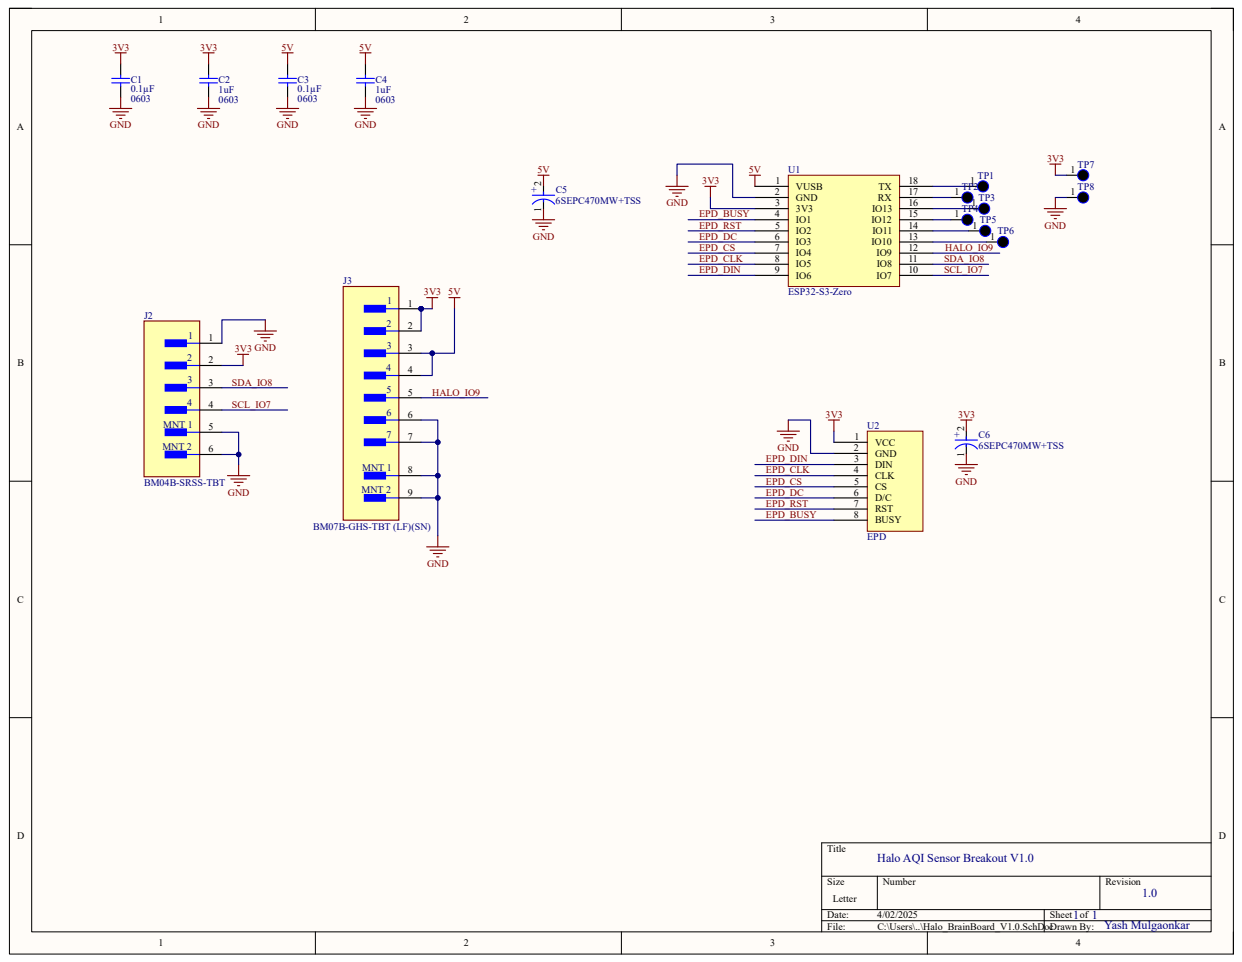
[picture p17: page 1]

BM07B-GHS-TBT (LF)(SN)

Halo AQI Sensor Breakout V1.0

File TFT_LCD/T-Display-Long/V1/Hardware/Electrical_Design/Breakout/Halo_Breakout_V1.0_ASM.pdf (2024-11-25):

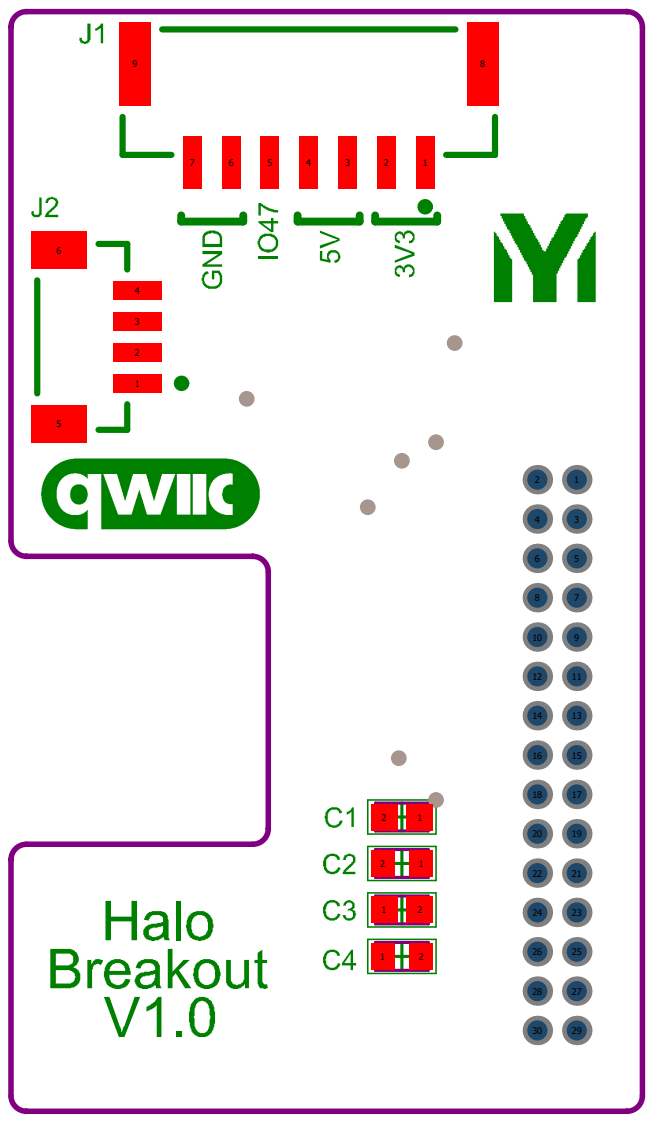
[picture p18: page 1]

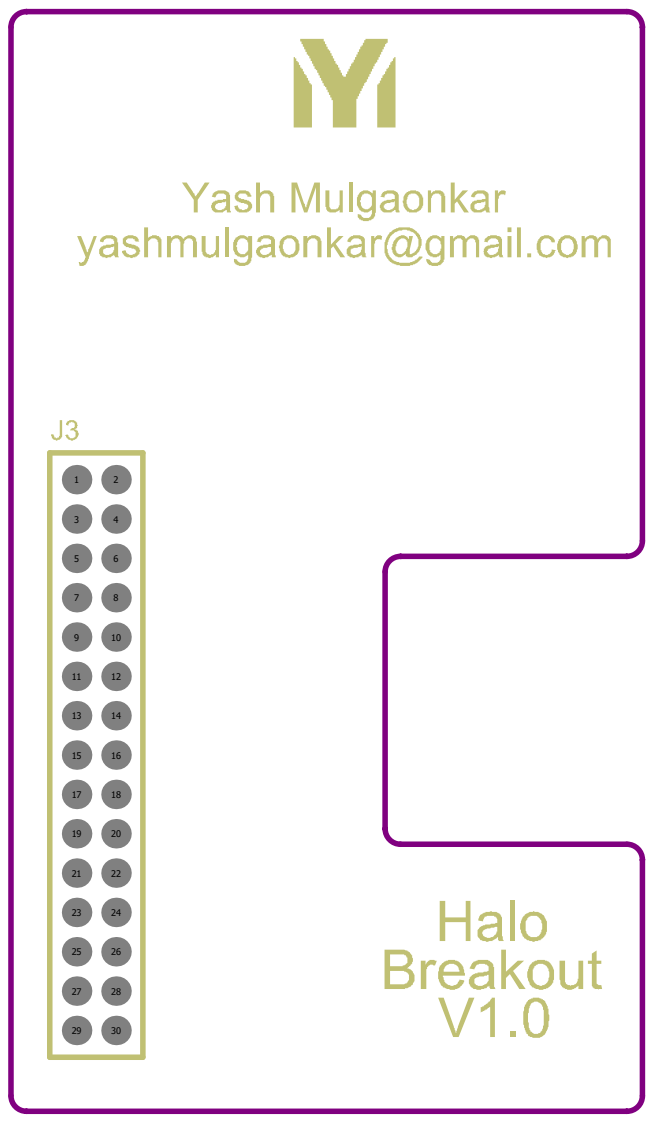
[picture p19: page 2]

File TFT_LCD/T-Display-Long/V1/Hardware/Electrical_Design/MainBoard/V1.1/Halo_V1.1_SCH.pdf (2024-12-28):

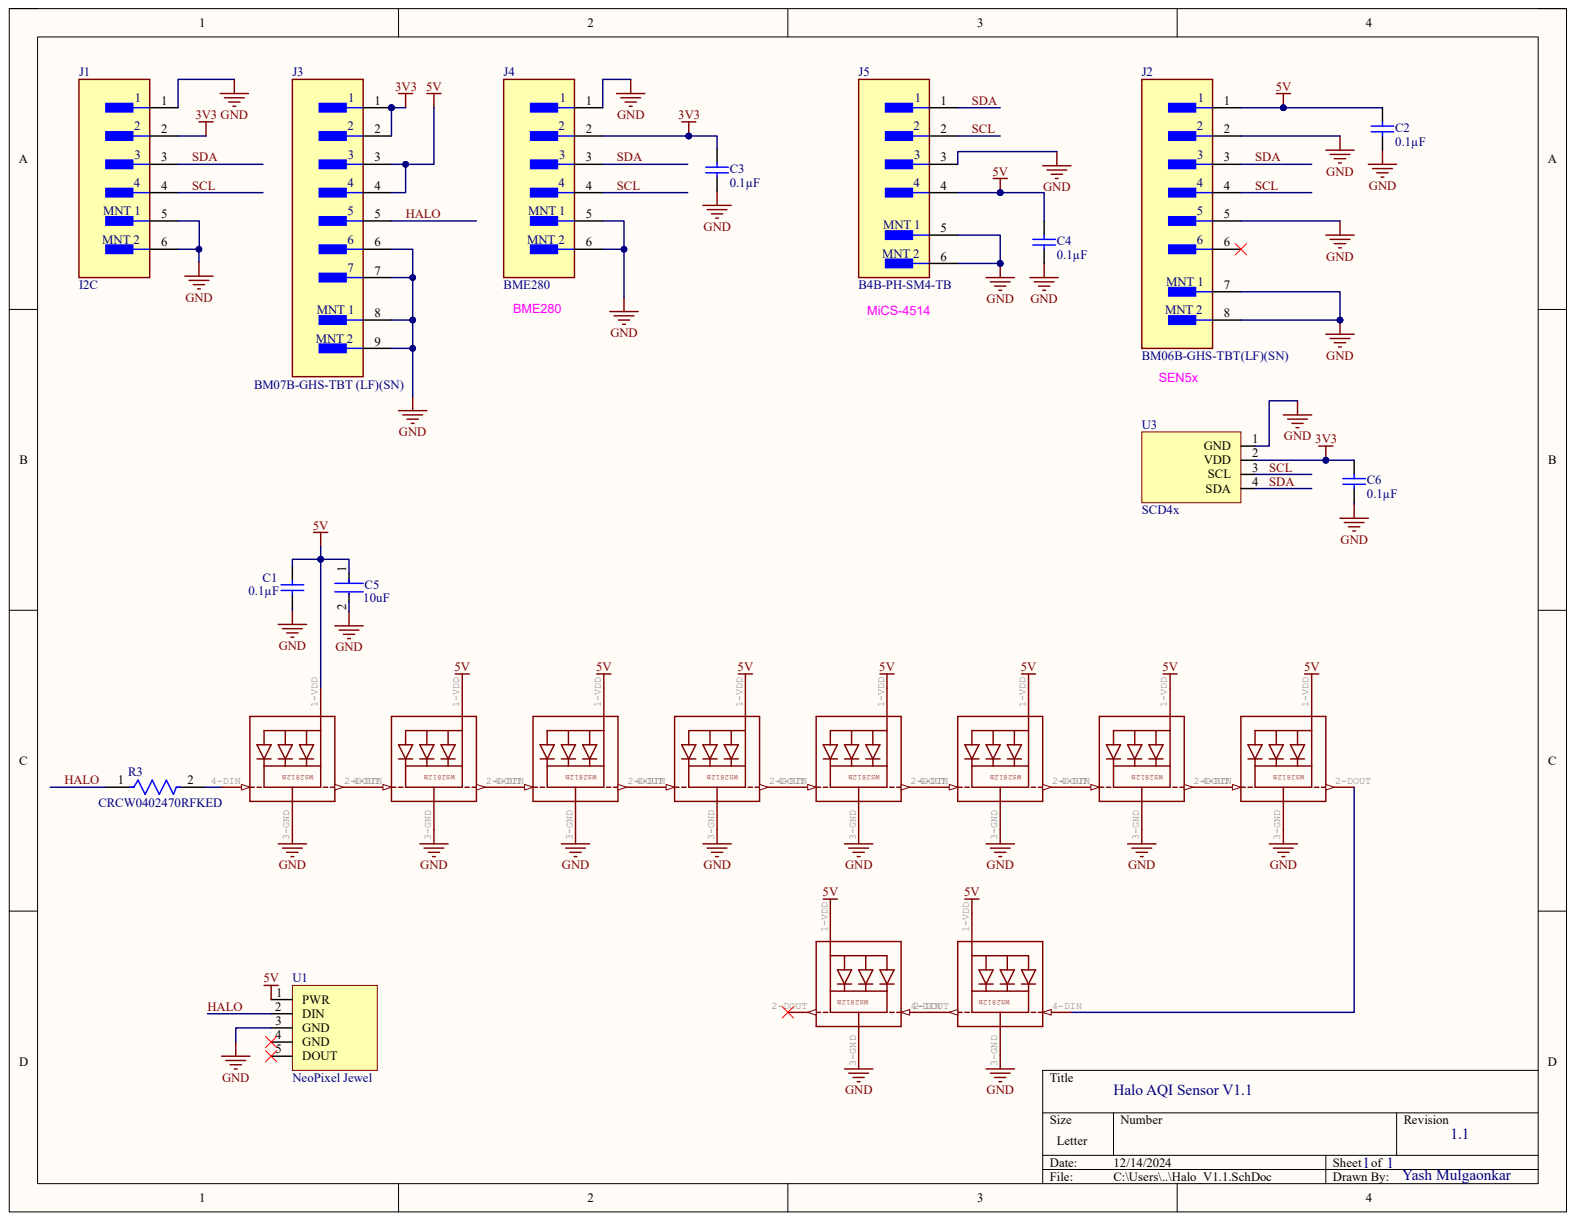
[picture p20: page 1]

BM07B-GHS-TBT (LF)(SN)

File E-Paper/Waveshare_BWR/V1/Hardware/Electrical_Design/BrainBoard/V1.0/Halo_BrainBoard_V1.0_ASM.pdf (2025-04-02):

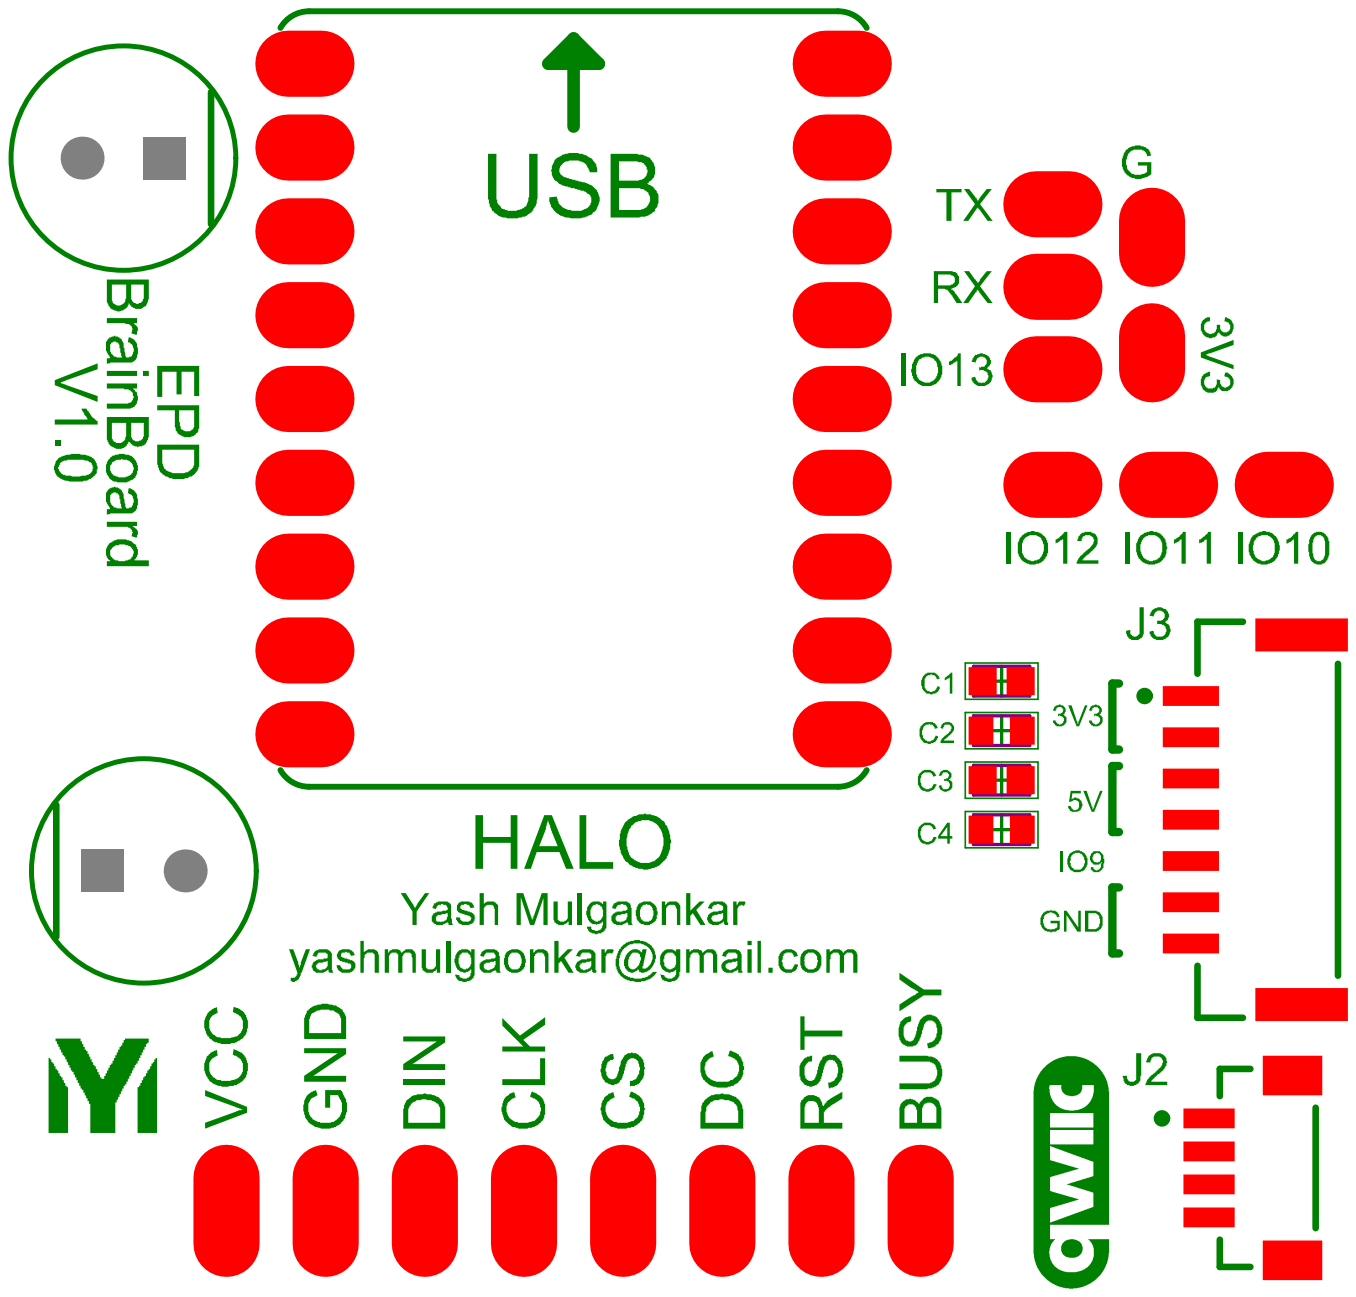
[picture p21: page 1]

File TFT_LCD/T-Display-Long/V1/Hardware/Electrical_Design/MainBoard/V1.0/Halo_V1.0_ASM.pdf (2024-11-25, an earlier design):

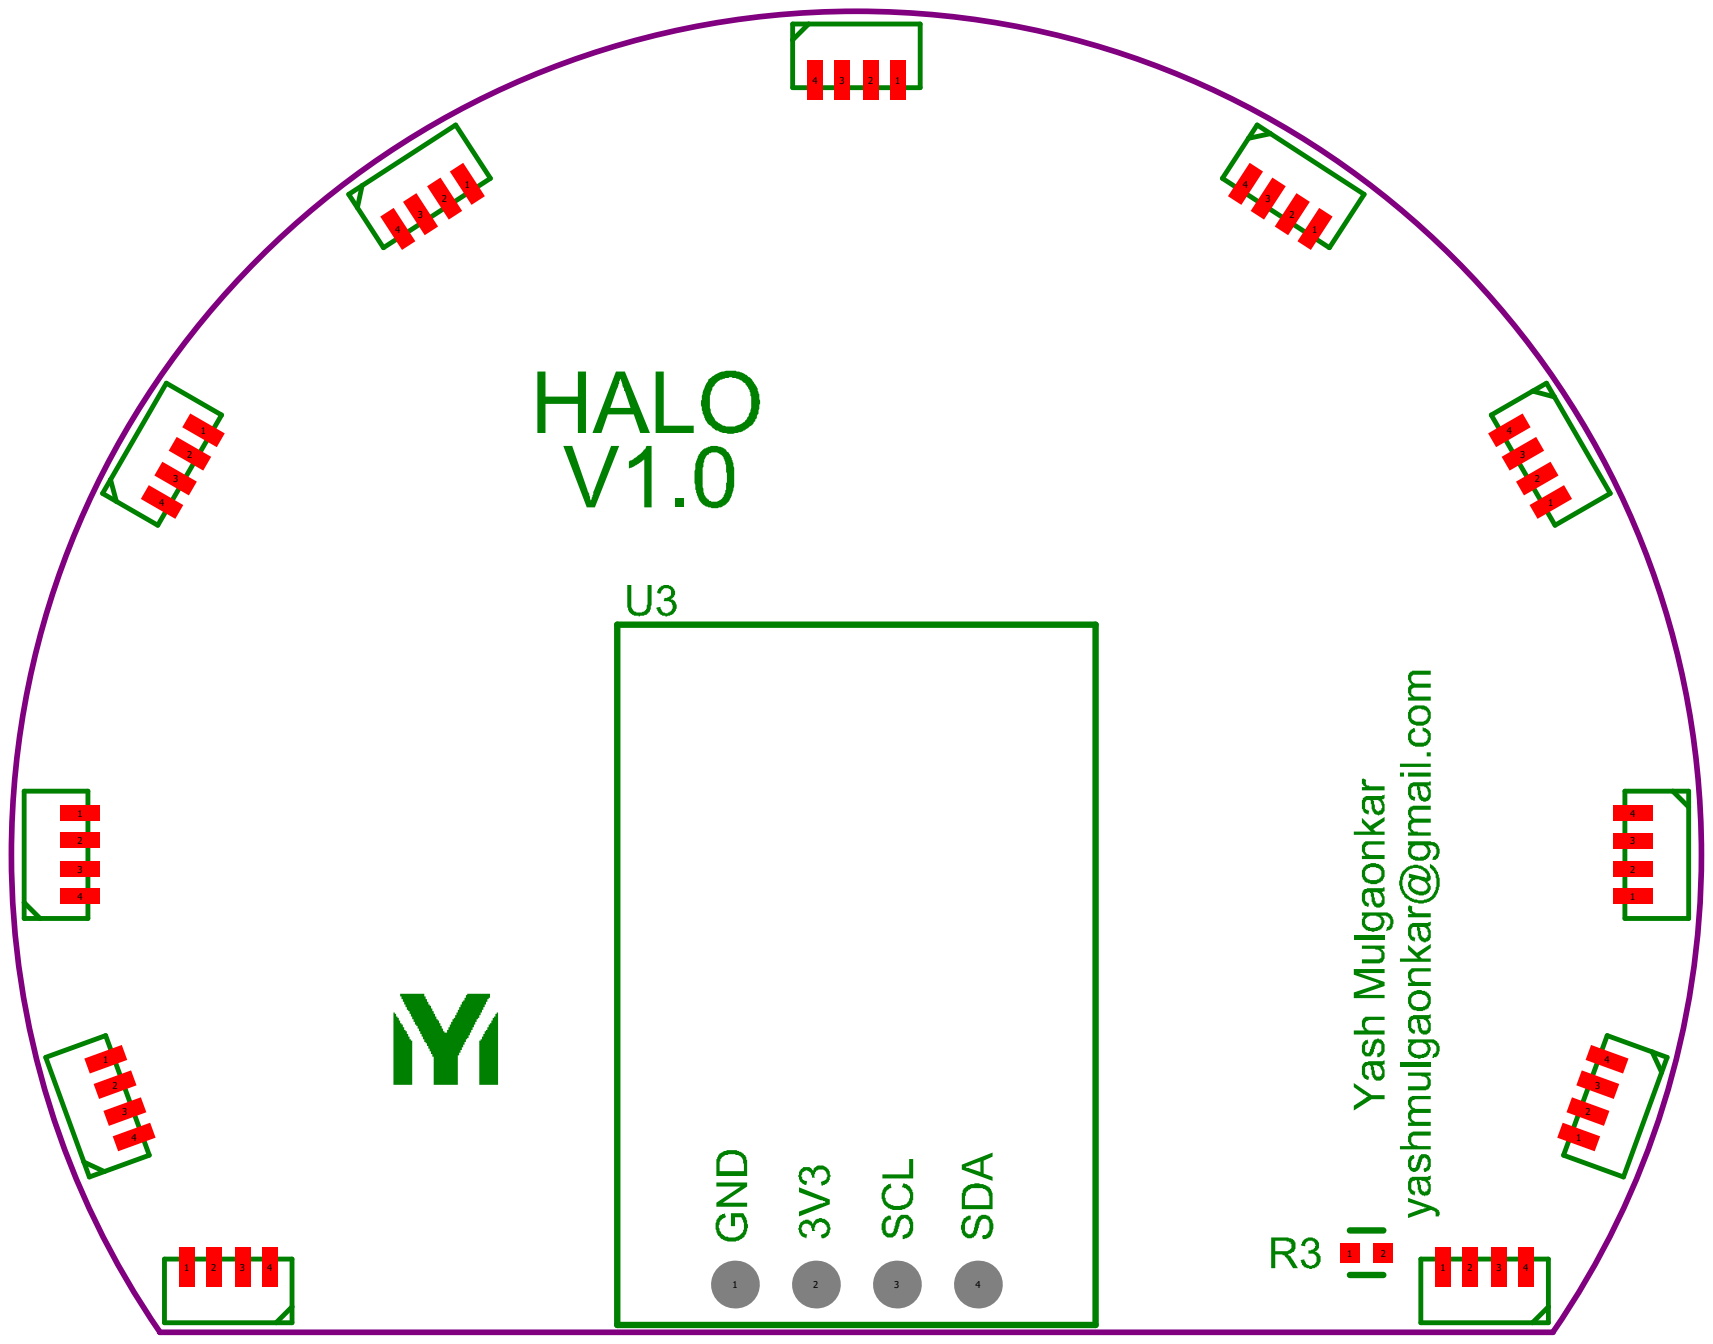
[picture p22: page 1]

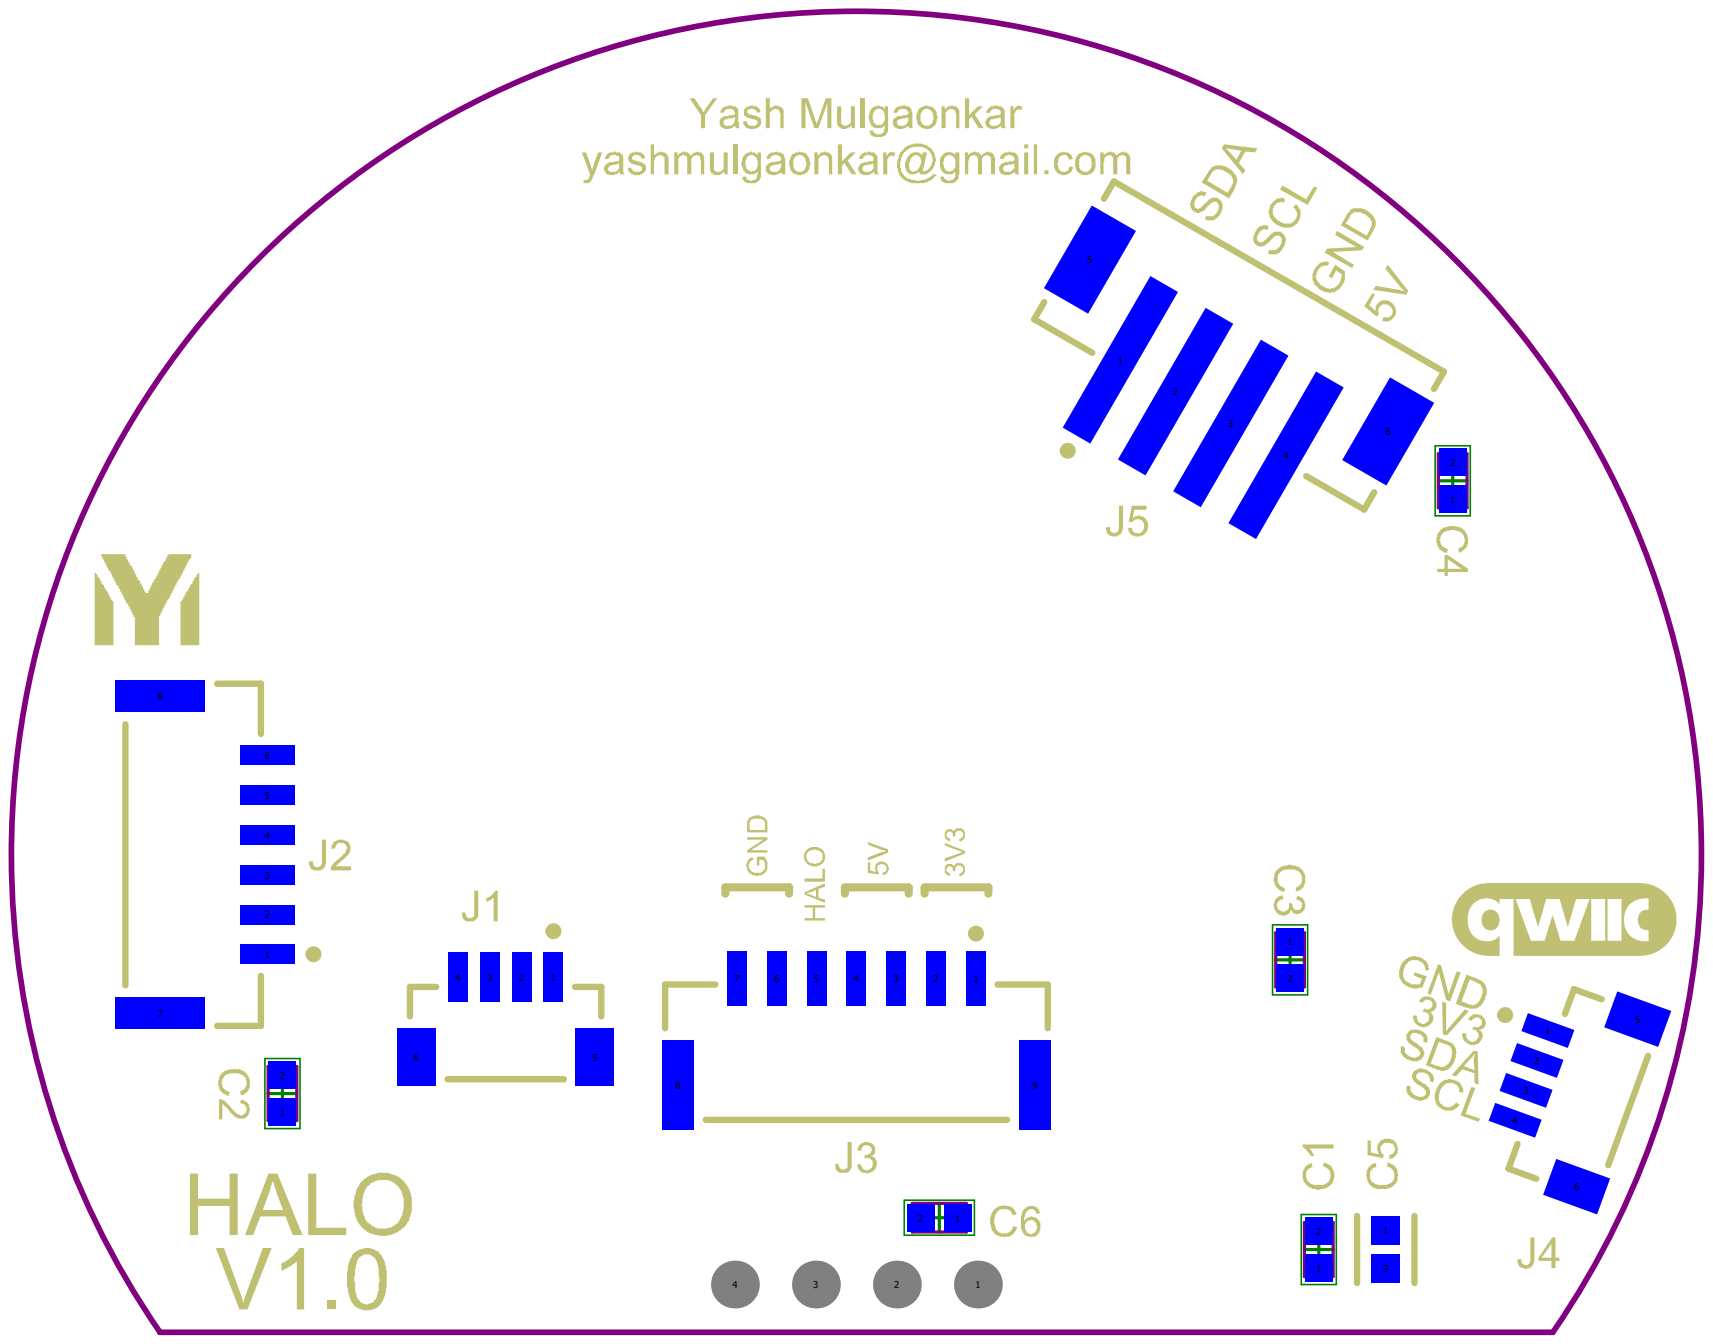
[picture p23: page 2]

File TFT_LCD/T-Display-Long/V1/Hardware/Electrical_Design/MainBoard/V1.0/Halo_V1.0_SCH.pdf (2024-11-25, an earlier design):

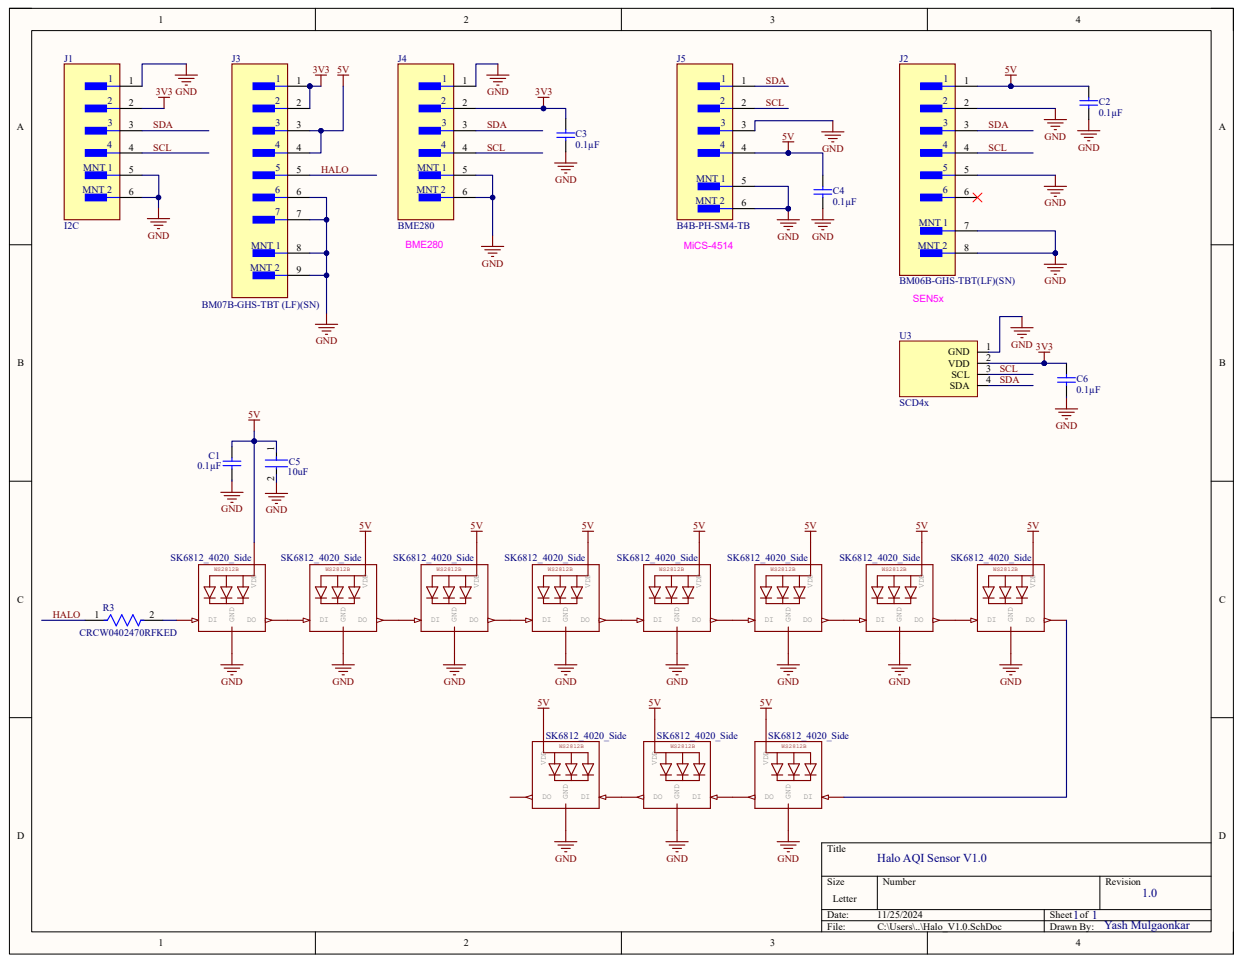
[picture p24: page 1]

BM07B-GHS-TBT (LF)(SN)

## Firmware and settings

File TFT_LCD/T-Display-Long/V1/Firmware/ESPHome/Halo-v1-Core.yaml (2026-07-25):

#Define Project
substitutions:
  name: halo
  version: "26.7.25.2"
  device_description: ${name} - v${version}.

# Project metadata must live here (not only in Halo-v1.yaml) so HA devices that
# pull leaf packages without Halo-v1.yaml still report the HALO release version.
esphome:
  project:
    name: "yashmulgaonkar.Halo-v1"
    version: "${version}"
  comment: "${device_description}"
  on_boot:
    - priority: -100
      then:
        - text_sensor.template.publish:
            id: halo_firmware_version
            state: "${version}"

# esp32 / psram / logger live in packages/system/esphome_core.yaml
# BLE / improv lives in packages/features/ble/ (pick one in Halo-v1.yaml).

# axs15231 touch is built into ESPHome; do not override with the external
# fork (its I2C write(..., stop) API breaks on 2026.7+).
# sy6970 remains available via github://yashmulgaonkar/esphome-components if needed.

spi:
  id: lily_spi
  type: quad
  clk_pin: 17
  data_pins:
    - 13
    - 18
    - 21
    - 14

captive_portal:

# Disable modem sleep — QSPI/AMOLED panels can blank after long uptime with default power save.
# use_psram: move Wi-Fi buffers out of internal SRAM (helps LED bitbang under load).
wifi:
  power_save_mode: none
  use_psram: true

# logger level comes from packages/system/esphome_core.yaml

globals:
  - id: cycleCounter
    type: int
    restore_value: no
    initial_value: '0'
  - id: temp_unit_changed
    type: bool
    initial_value: "true"

switch:
  - platform: template
    name: "Startup Light Blink"
    id: startup_light_blink
    icon: mdi:lightbulb
    restore_mode: RESTORE_DEFAULT_ON
    optimistic: true
    entity_category: "config"
  - platform: template
    name: "24h Clock Format"
    id: time_format
    icon: mdi:clock-digital
    restore_mode: RESTORE_DEFAULT_OFF
    optimistic: true
    entity_category: "config"
  # SCD4x forgets ASC across power loss; YAML default is re-applied at setup.
  # Use stop → write ASC → start so the sensor accepts the command while idle.
  - platform: template
    name: "CO2 Auto Calibration"
    id: co2_auto_calibration
    icon: mdi:molecule-co2
    restore_mode: RESTORE_DEFAULT_OFF
    optimistic: true
    entity_category: "config"
    on_turn_on:
      then:
        - script.execute:
            id: set_co2_auto_calibration
            enable: true
    on_turn_off:
      then:
        - script.execute:
            id: set_co2_auto_calibration
            enable: false

select:
  - platform: template
    name: Display Temperature Unit
    id: display_temperature_unit
    entity_category: "Config"
    options:
     - "Fahrenheit"
     - "Celsius"
     - "Kelvin"
    initial_option: "Fahrenheit"
    restore_value: true
    optimistic: true
    on_value:
      - globals.set:
          id: temp_unit_changed
          value: "true"

interval:
  - interval: 10s
    then:    
      if:
        condition:
          wifi.connected:
        then:
          - lvgl.widget.update:
              id: wifi_stat
              text_color: my_green
          - lvgl.widget.show:
              id: ym_image              
        else:
          - lvgl.widget.update:
              id: wifi_stat
              text_color: my_red

  - interval: 1s
    then:
      - script.execute: time_update  

  - interval: 1s
    then:
      - if:
          condition:
            - binary_sensor.is_off: ink_ha_connected
            - lambda: 'return id(cycleCounter) < 30;'
            - switch.is_on: startup_light_blink

          then:
            - light.turn_on:
                id: rgb_light
                effect: "Addressable Rainbow"
            - lambda: 'id(cycleCounter) += 1;'

  - interval: 1s
    then:
      - if:
          condition:
            - binary_sensor.is_off: ink_ha_connected
            - lambda: 'return id(cycleCounter) > 30;'
            - lambda: 'return id(cycleCounter) < 31;'
            - switch.is_on: startup_light_blink

          then:
            - light.turn_off:
                id: rgb_light
            # Leave a white color state so the next HA turn_on isn't pure blue.
            - light.turn_on:
                id: rgb_light
                brightness: 0%
                red: 100%
                green: 100%
                blue: 100%
                effect: "None"
            - light.turn_off:
                id: rgb_light
            - lambda: 'id(cycleCounter) += 1;'
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

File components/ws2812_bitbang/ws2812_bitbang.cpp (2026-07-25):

#include "ws2812_bitbang.h"

#ifdef USE_ESP32

#include "esphome/core/log.h"

#include <cinttypes>
#include <esp_cpu.h>
#include <esp_ipc.h>
#include <esp_rom_sys.h>
#include <freertos/FreeRTOS.h>
#include <freertos/portmacro.h>
#include <hal/gpio_ll.h>
#include <soc/gpio_struct.h>

namespace esphome::ws2812_bitbang {

static const char *const TAG = "ws2812_bitbang";

// Adafruit NEO_KHZ800 cycle counts at CONFIG_ESP_DEFAULT_CPU_FREQ_MHZ.
static inline uint32_t cycles_t0h() { return CONFIG_ESP_DEFAULT_CPU_FREQ_MHZ * 1000000U / 2500000U; }
static inline uint32_t cycles_t1h() { return CONFIG_ESP_DEFAULT_CPU_FREQ_MHZ * 1000000U / 1250000U; }
static inline uint32_t cycles_period() { return CONFIG_ESP_DEFAULT_CPU_FREQ_MHZ * 1000000U / 800000U; }

// Dual-core hold: Wi-Fi on the other core still jitters the flash/PSRAM bus
// even when this core has IRQs masked — that was the leftover sparkle.
struct DualCoreHold {
  volatile uint32_t stage;  // 0 idle, 1 other-core frozen, 2 release
};

static DualCoreHold s_hold{0};

// portDISABLE_INTERRUPTS only raises INTLEVEL to 3 — Wi-Fi MAC/timer interrupts
// at level 4+ still preempt mid-bit (the residual "minor flicker"). RSIL 15
// masks every maskable level on Xtensa LX7.
static inline IRAM_ATTR uint32_t intlevel_mask_all() {
  uint32_t ps;
  __asm__ __volatile__("rsil %0, 15" : "=r"(ps));
  return ps;
}
static inline IRAM_ATTR void intlevel_restore(uint32_t ps) {
  __asm__ __volatile__("wsr.ps %0 \n rsync" ::"r"(ps));
}

static void IRAM_ATTR HOT ipc_freeze_other_core(void *arg) {
  auto *h = static_cast<DualCoreHold *>(arg);
  uint32_t ps = intlevel_mask_all();
  h->stage = 1;
  while (h->stage != 2) {
  }
  intlevel_restore(ps);
}

static inline IRAM_ATTR void gpio47_high() { GPIO.out1_w1ts.val = (1u << (47 - 32)); }
static inline IRAM_ATTR void gpio47_low() { GPIO.out1_w1tc.val = (1u << (47 - 32)); }

static inline IRAM_ATTR void gpio_any_high(uint8_t pin) { gpio_ll_set_level(&GPIO, pin, 1); }
static inline IRAM_ATTR void gpio_any_low(uint8_t pin) { gpio_ll_set_level(&GPIO, pin, 0); }

void WS2812BitbangLightOutput::setup() {
  size_t buffer_size = this->get_buffer_size_();
  RAMAllocator<uint8_t> allocator(RAMAllocator<uint8_t>::ALLOC_INTERNAL);
  this->buf_ = allocator.allocate(buffer_size);
  if (this->buf_ == nullptr) {
    ESP_LOGE(TAG, "Cannot allocate LED buffer");
    this->mark_failed();
    return;
  }
  memset(this->buf_, 0, buffer_size);

  this->effect_data_ = allocator.allocate(this->num_leds_);
  if (this->effect_data_ == nullptr) {
    ESP_LOGE(TAG, "Cannot allocate effect data");
    this->mark_failed();
    return;
  }
  memset(this->effect_data_, 0, this->num_leds_);

  gpio_config_t cfg = {};
  cfg.pin_bit_mask = 1ULL << this->pin_;
  cfg.mode = GPIO_MODE_OUTPUT;
  cfg.pull_up_en = GPIO_PULLUP_DISABLE;
  cfg.pull_down_en = GPIO_PULLDOWN_DISABLE;
  cfg.intr_type = GPIO_INTR_DISABLE;
  gpio_config(&cfg);
  gpio_set_level(static_cast<gpio_num_t>(this->pin_), 0);
}

void IRAM_ATTR HOT WS2812BitbangLightOutput::show_() {
  const uint8_t *p = this->buf_;
  const uint8_t *end = p + this->get_buffer_size_();
  const uint8_t pin = this->pin_;
  const bool pin47 = (pin == 47);
  const uint32_t t0h = cycles_t0h();
  const uint32_t t1h = cycles_t1h();
  const uint32_t period = cycles_period();

  // Freeze the other CPU so Wi-Fi DMA/cache can't stretch bit timing.
  s_hold.stage = 0;
  const int other = (xPortGetCoreID() == 0) ? 1 : 0;
  esp_err_t ipc = esp_ipc_call(other, ipc_freeze_other_core, &s_hold);
  if (ipc == ESP_OK) {
    uint32_t spin = 0;
    while (s_hold.stage != 1 && spin++ < 1000000u) {
    }
  }

  uint32_t ps = intlevel_mask_all();

  while (p < end) {
    uint8_t b = *p++;
    for (int i = 7; i >= 0; i--) {
      uint32_t start = esp_cpu_get_cycle_count();
      uint32_t high = (b & (1 << i)) ? t1h : t0h;
      if (pin47) {
        gpio47_high();
      } else {
        gpio_any_high(pin);
      }
      while ((esp_cpu_get_cycle_count() - start) < high) {
      }
      if (pin47) {
        gpio47_low();
      } else {
        gpio_any_low(pin);
      }
      while ((esp_cpu_get_cycle_count() - start) < period) {
      }
    }
  }

  intlevel_restore(ps);
  s_hold.stage = 2;  // release other core
  esp_rom_delay_us(60);
}

void WS2812BitbangLightOutput::write_state(light::LightState *state) {
  uint32_t now = micros();
  auto rate = this->max_refresh_rate_.value_or(0);
  if (rate != 0 && (now - this->last_refresh_) < rate) {
    this->schedule_show();
    return;
  }
  this->last_refresh_ = now;
  this->mark_shown_();
  this->show_();
  this->status_clear_warning();
}

light::ESPColorView WS2812BitbangLightOutput::get_view_internal(int32_t index) const {
  int32_t r = 0, g = 1, b = 2;
  switch (this->rgb_order_) {
    case ORDER_RGB:
      r = 0;
      g = 1;
      b = 2;
      break;
    case ORDER_RBG:
      r = 0;
      g = 2;
      b = 1;
      break;
    case ORDER_GRB:
      r = 1;
      g = 0;
      b = 2;
      break;
    case ORDER_GBR:
      r = 2;
      g = 0;
      b = 1;
      break;
    case ORDER_BGR:
      r = 2;
      g = 1;
      b = 0;
      break;
    case ORDER_BRG:
      r = 1;
      g = 2;
      b = 0;
      break;
  }
  return {this->buf_ + (index * 3) + r, this->buf_ + (index * 3) + g, this->buf_ + (index * 3) + b, nullptr,
          &this->effect_data_[index], &this->correction_};
}

void WS2812BitbangLightOutput::dump_config() {
  ESP_LOGCONFIG(TAG,
                "WS2812 bitbang (dual-core IRQ hold):\n"
                "  Pin: %u\n"
                "  Num LEDs: %u\n"
                "  Max refresh rate: %" PRIu32,
                this->pin_, this->num_leds_, this->max_refresh_rate_.value_or(0));
}

}  // namespace esphome::ws2812_bitbang

#endif

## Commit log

2024-11-25 Adding PCB files
    [Halo_Breakout_V1.0.csv, Halo_V1.0_BOM.csv]
2024-11-25 adding PCB renders
2024-11-25 renaming BOM
    [Halo_Breakout_V1.0_BOM.csv]
2024-11-27 changing folder structure
    [Halo_Breakout_V1.0_BOM.csv, Halo_V1.0_BOM.csv]
2024-12-08 updating pin mapping and halo color thresholds for AQI
2024-12-09 Adding STL files.
    [HALO_base.STL, HALO_light_diffuser.STL, HALO_outer_shell.STL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]
2024-12-09 Adding mesh STLs
    [HALO_side_mesh.STL, HALO_top_mesh.STL]
2024-12-10 adding pcb renders
2024-12-10 updating pcb renders
2024-12-10 Adding CO2 Sensor spacer
    [HALO_CO2_spacer.STL]
2024-12-25 Fixing temperature unit bug and removing yaml Halo control
2024-12-28 Adding MainBoard V1.1
    [Halo_V1.0_BOM.csv, Halo_V1.1_BOM.csv, Pick Place for Halo_V1.1.csv]
2025-01-02 Adding pick and place for BreakoutBoard
    [Pick Place for Halo_Breakout_V1.0.csv]
2025-01-08 Removing uploaded STL files and maintaining them on MakerWorld and Printables instead
    [HALO_CO2_spacer.STL, HALO_base.STL, HALO_light_diffuser.STL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]
2025-01-16 Restructuring repo based on hardware features
    [Halo_Breakout_V1.0_BOM.csv, Halo_V1.0_BOM.csv, Halo_V1.1_BOM.csv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]
2025-01-16 Restructuring repo to separate display types
    [Halo_Breakout_V1.0_BOM.csv, Halo_V1.0_BOM.csv, Halo_V1.1_BOM.csv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]
2025-02-16 fix touch i2c and add display temp unit selection
    [Halo-v1-Core.yaml]
2025-02-18 fix off by one in temp range, great eyes @TerraIncognito-sudo
    [Halo-v1-Core.yaml]
2025-03-01 fix for breaking changes for ESPHome 2025.2.1
    [Halo-v1-Core.yaml]
2025-03-01 Fix for breaking changes for esp32_rmt_led_strip
    [Halo-v1-Core.yaml]
2025-03-05 Expose pin 1 as ledc output to control backlight via ESPHome
2025-03-11 Lowering backlight PWM to improve stability
    https://github.com/yashmulgaonkar/halo/pull/12#issue-2905623325
    [Halo-v1-Core.yaml]
2025-03-16 SY6970 status LED turned off.
2025-03-17 fixed temperature units label
    [Halo_EPD-Core.yaml]
2025-03-28 updating Halo pin
2025-03-28 updating I2C GPIO for EPD
2025-04-02 Adding PCB files for EPD Halo.
    [Halo_BrainBoard_V1.0_BOM.csv, Halo_BrainBoard_V1.0_PickPlace.csv]
2025-04-20 Fixing “120MHz is not supported in octal mode”
    [Halo-v1-Core.yaml]
2025-05-15 fixing octal changes in ESPHome
    [Halo-v1-Core.yaml]
2025-08-23 updating ESP32 cpu freq
2025-08-29 updating workflow to create missing manifest
    [Halo-v1-Core.yaml, Halo_EPD-Core.yaml]
2025-09-08 Revert "slow down refresh rates and reduce lvgl buffer size."
    This reverts commit e41285c83fd745ced86379a19a12544ee8f8770c.
    [Halo-v1-Core.yaml]
2026-01-04 Add MICS4514 NO2 offset configuration
    - Add NO2 offset template number entity (range: ±1.0 ppm, step: 0.01 ppm)
    - Apply offset filter to nitrogen_dioxide sensor readings
    - Follow same pattern as existing SEN55 temperature/humidity offsets
    - Bump version to 25.9.8.2
2026-01-10 updating workflow and correcting version number
    [Halo-v1-Core.yaml]
2026-07-24 Fix display blanking and make CI build the branch under test.
    Disable WiFi power save and cut LVGL buffer to 50%, switch packages to sibling !include so branch/CI builds use local Core, and only publish releases/Pages from main.
    [Halo-v1-Core.yaml]
2026-07-24 Remove stale pr#7770 RMT external component that breaks esp32_rmt_led_strip.
2026-07-24 Fix ota_default redefine and migrate image to platform: file.
    [Halo-v1-Core.yaml]
2026-07-24 Switch RGB ring to neopixelbus to avoid esp32_rmt_led_strip platform errors.
    [Halo-v1-Core.yaml]
2026-07-24 Revert image platform:file for ESPHome 2026.6/7 compat; pin CI to 2026.7.2.
    [Halo-v1-Core.yaml]
2026-07-24 Restore esp32_rmt_led_strip for esp-idf; use image platform:file on 2026.7.2.
2026-07-24 Fix startup blink effect name to match Addressable Rainbow.
    [Halo-v1-Core.yaml]
2026-07-24 Use built-in axs15231 touchscreen; drop incompatible external fork.
    [Halo-v1-Core.yaml]
2026-07-24 Migrate select.state to current_option() for ESPHome 2026.7.
2026-07-24 Compare select current_option() as StringRef, not const char*.
2026-07-24 Reduce RGB ring flicker in rainbow mode on T-Display-S3-Long.
    Keep the RMT LED buffer out of PSRAM, enable DMA, and cap refresh rate to avoid QSPI contention with the display.
    [Halo-v1-Core.yaml]
2026-07-24 adding led timing
2026-07-25 adding fixed color test to halo
    [Halo-v1-Core.yaml]
2026-07-25 testing 5 leds
2026-07-25 reconfig leds
2026-07-25 isolating LEDs
2026-07-25 Fix NeoPixel ring flicker under Wi-Fi with ws2812_bitbang driver
    [Halo-v1-Core.yaml, ws2812_bitbang.cpp]
2026-10-28 Saturate the AQI and CO2 ring colors and keep the device page out of rotation.
2026-10-30 Rebuild the device portal and keep large readings clear of their labels.
2026-10-30 Pin the LVGL build to the ESP32 core the ring driver uses.
2026-11-09 Fix/ha mqtt sensor states (#30)
    * Report PM2.5 and PM10 in µg/m³ so Home Assistant accepts their discovery.
    Home Assistant rejects an MQTT sensor whose unit does not match its device
    class, and the pm25 and pm10 classes only allow µg/m³. With ug/m3 both
    entities were dropped and the log showed "The unit of measurement `ug/m3`
    is not valid together with device class `pm25`".
    * Publish None for a missing reading so Home Assistant shows it as unknown.
    The literal string "unavailable" is not numeric, so every publish for a
    sensor without a reading (the gas channels while warming up) logged a value
    error and the entity never changed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
2026-11-10 Track fast and right-going swipes by comparing each touch sample with the previous one. (#31)
    A touch needed three samples within 24 px of the first, so a quick swipe
    (over 24 px per 30 ms poll) restarted the count and was never tracked.
    Compare with the previous sample, allow up to kJumpPx along X while keeping
    the 24 px Y limit that rejects stray reads, and measure the swipe from where
    the finger landed.
2026-11-10 Put CO2 under the AQI block and tighten the TEMP and HUMIDITY blocks. (#32)
    CO2 now follows the AQI card on the Air page. In the TEMP and HUMIDITY cards
    the value sits 3 px lower and the unit 5 px higher with the tag unchanged, and
    the status bars are 22 px long to match the PM rows and PRES.
2026-11-11 Only publish sensor values to MQTT when they change meaningfully (#34) [skip release]
    Deadband MQTT sensor updates, and retry a publish that failed.
2026-11-11 Drop a phantom stationary touch and keep an on-device event log. (#38)
    The touch panel sometimes reports a press that never moves (seen at one spot
    for minutes). While a contact is held the driver ignores any jump away from it,
    so real touches were lost, and its long press opened the gas offset editor,
    which blocks swiping.
    A contact that stays within 14 px for 3 s is now dropped, its spot (30 px
    radius) is ignored until nothing has been seen there for 2 s, and an editor
    opened by that press is closed.
    The event log lives in RTC memory, so it survives a crash or reset, and
    important lines are copied to flash so they survive a power cycle. It records
    boots and reset reasons, page changes an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
2026-11-11 Add a weather screen left of the air page, and a temperature unit toggle on Device. [skip release] (#41)
    Weather comes from Open-Meteo (key-less, CC BY 4.0, credit shown on screen). A
    background task on core 0 fetches every 30 minutes over verified TLS, so the
    display and touch loop are never blocked. A new TLS lock makes the weather
    fetch, the update check and the firmware download take turns. Retries back off
    up to 10 minutes and never run closer than a minute apart, which keeps the
    free tier (under 10,000 calls a day) safe even if a fetch keeps failing.
    The screen has a tinted hero card with a condition icon drawn from LVGL shapes,
    the temperature, feels-like, humidity and wind, sunrise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
2026-11-11 Keep a ring effect or colour chosen in Home Assistant instead of cancelling it. (#42)
    main calls ring().showAir() on every loop, and showAir reset the effect to None
    and overwrote the colour, so an effect picked in Home Assistant was gone within
    a few milliseconds. The effect list was offered but nothing stuck.
    showAir now leaves the effect alone. Pulse, Scan and Twinkle take the air
    quality colour, and Rainbow and Color Wipe use their own. A colour set from
    Home Assistant or the portal now stays until the light is turned off, which
    hands the colour back to the air quality.
    The portal's /api/state also reports ring_on, ring_effect, ring_rgb and
    ring_custom so the ring can be checked withou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
2026-11-11 Configure the SY6970 power chip so the T-Display-S3-Long stops browning out. (#40)
    The board feeds everything through an SY6970 charger at 0x6A on the touch bus.
    The firmware never set it up, so it stayed at its power-on defaults: input
    current capped at 500 mA by the ILIM pin (REG00=0x48), and the battery FET on
    with no battery fitted, so the charger keeps hunting for one. When the ring,
    SEN5x fan, Wi-Fi and display together pass 500 mA, SYS sags and the ESP32
    resets with reset=power-on. On one unit this gave a restart every 1-3 minutes
    (far more often with the backlight at 0), and the OTA download never finished,
    leaving app1 with no image header.
    At boot the firmware now does what LilyGO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
2026-11-12 Resend discovery and state when Home Assistant comes online. [skip release]
    HALO subscribes to homeassistant/status and resends discovery, sensor values, ring and backlight when HA publishes online.
2026-11-12 Split the web portal into labelled sections with live readings. [skip release] (#45)
    Night mode is Off, Auto or Custom. Ring, night mode, location and device actions are separate sections. Readings refresh in the background.
2026-11-12 Show the device name on the Device page.
    Adds the halo-xxxxxx hostname to the Device page.
2026-11-12 README tweaks. [skip release]
    Coffee button to the top, placeholders trimmed.
